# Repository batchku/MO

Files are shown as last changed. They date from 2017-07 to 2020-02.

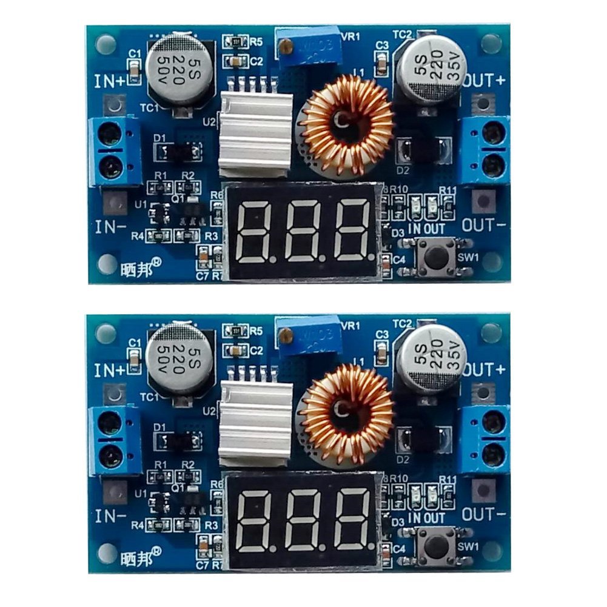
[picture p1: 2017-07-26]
PCBs/MO/_Pictures/PowerConv.jpg

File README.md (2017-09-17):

# MO
Mobile Objects for Music (MOM), Mobile Object for Drawing (MOD), and ...

## Installation

First: clone this repo:
```
git clone git@github.com:batchku/MO.git
```

Then: This repo relies on a [aLib-pd](https://github.com/batchku/aLib-pd) as a submodule. You can either clone that repo separately, or use this command within the MO repository to pull the submodule:

```
git submodule update --init --recursive
```
### nameChange.sh

To test for resulting name change use "test":

```./nameChanger.sh test searchTerm wordToReplaceWith```

To actually change use "change":

```./nameChanger.sh change searchTerm wordToReplaceWith```

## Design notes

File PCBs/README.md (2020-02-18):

# PCBs
###   GERBERS
Gerber files for PCB orders
###   MO
Board + Schem files for MO, this is the primary PCB collection
###   MOM
Board + Schem files specifically for MOM
###   Processor
Header, .txt, and XML file generator code

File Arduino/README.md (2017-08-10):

# Arduino
### MOD
Code base for MO modular system
### MOM
Code for MOM versions prior to MO modular system

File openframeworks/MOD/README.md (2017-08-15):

# livedraw-mini
openFrameworks based live video looper made for the Raspberry Pi 3, with a Pi Camera v2

# code
`ConsoleListener.h` - used for debugging in console on the Pi
`Consts.h` - definition of application parameters
`main.cpp` - application; set up openGL context, link to main class
`ofApp.cpp` - main functions for init, update and draw
`ofApp.h` - goes with ofApp.cpp
`Utils.cpp` - helper functions for math and such
`Utils.h` - goes with Utils.cpp
`vidLayer.cpp` - main class to handle a video layer; includes memory allocaiton, rendering, updating, and real-time control
`vidLayer.h` - goes with vidLayer.cpp

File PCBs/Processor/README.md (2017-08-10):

# Pin Mapping Generator
This python script generates the following header files for the arduino program [MOD.ino](https://github.com/batchku/MO/blob/master/Arduino/MOD/MOD.ino):
- [MO.H](https://github.com/batchku/MO/blob/master/PCBs/Processor/MO.h): defines a variable for each used pin
- [ARRAYS.H](https://github.com/batchku/MO/blob/master/PCBs/Processor/ARRAYS.h): defines arrays of all the related variables for easier coding
- [MIDI.h](https://github.com/batchku/MO/blob/master/PCBs/Processor/MIDI.h): defines midi note and control numbers for each pin

It also generates a text file for the [MO Pd abstractions](https://github.com/batchku/MO/tree/master/Pd/MO)
- [inputs.txt](https://github.com/batchku/MO/blob/master/PCBs/Processor/inputs.txt): defines MIDI values for UI elements in abstractions

# Coming...
- XML file for openFrameworks for MIDI mapping
- 

# Usage
1.  export a pinlist from eagle schematic, here called inputfile
2.  execute:
        ```python3 createFiles.py intputfile```

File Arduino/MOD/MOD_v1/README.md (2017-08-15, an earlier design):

# MOD Arduino code
Currently the MOD is hard-coded.

MIDI.h and MOD.h can be used from the [generator script](https://github.com/batchku/MO/blob/master/PCBs/Processor/createFiles.py) but DO NOT replace [Arrays.h](https://github.com/batchku/MO/blob/master/Arduino/MOD/Arrays.h).

In Tools of Arduino set:
* ```Board:``` to ```Teensy 3.6```
* ```USB Type:``` to ```Serial + MIDI```

# Coming Soon...
Modular class system for each aspect of the hardware. Classes will include: 
1. Strip
2. Actuator
3. User Interface (for components on shield)

### Ignore (for now)
* Strip.cpp/Strip.h
* MOBasic.cpp/MOBasic.h

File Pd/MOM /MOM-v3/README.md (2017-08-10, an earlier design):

# MOM
Running Puredata on the Raspberry Pi 3 computer

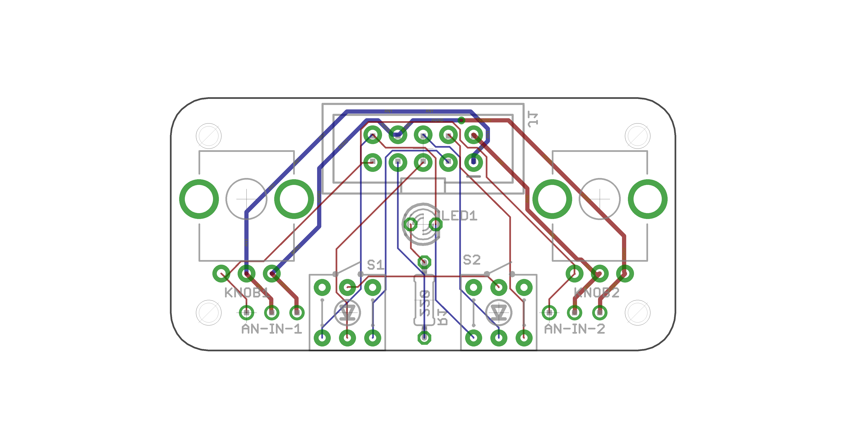
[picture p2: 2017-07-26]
PCBs/MO/_Pictures/MOD-v2-1_MOD-Strips.png

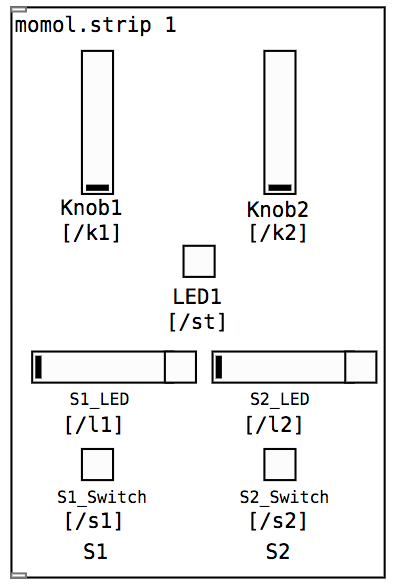
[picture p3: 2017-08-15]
Documentation/mo.strip.png

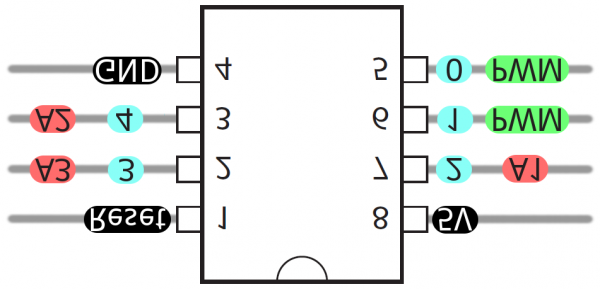
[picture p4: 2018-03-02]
Arduino/Raspi_Power_Tiny/tiny85.png

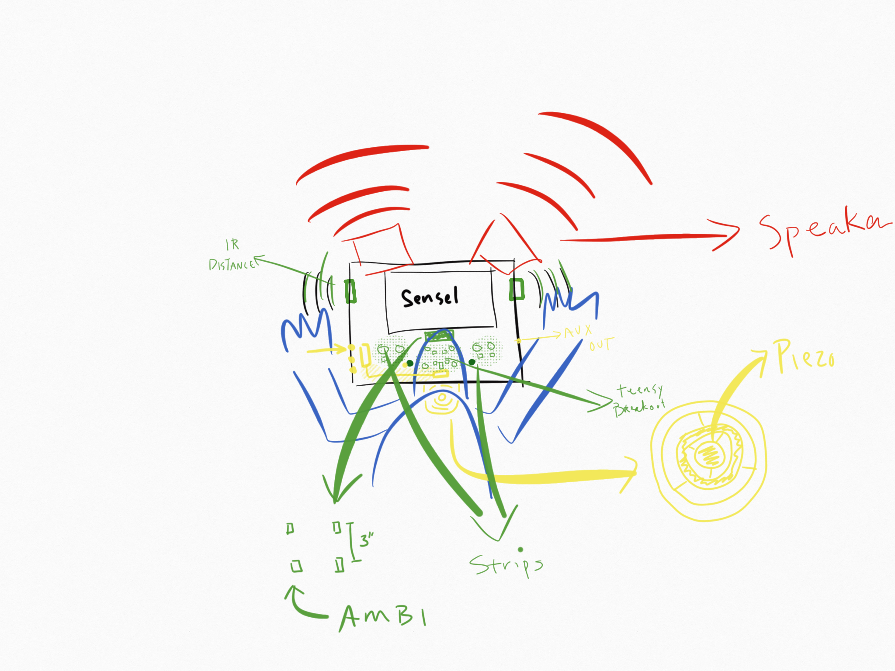
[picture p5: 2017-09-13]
Documentation/MOM_Sketch.jpg

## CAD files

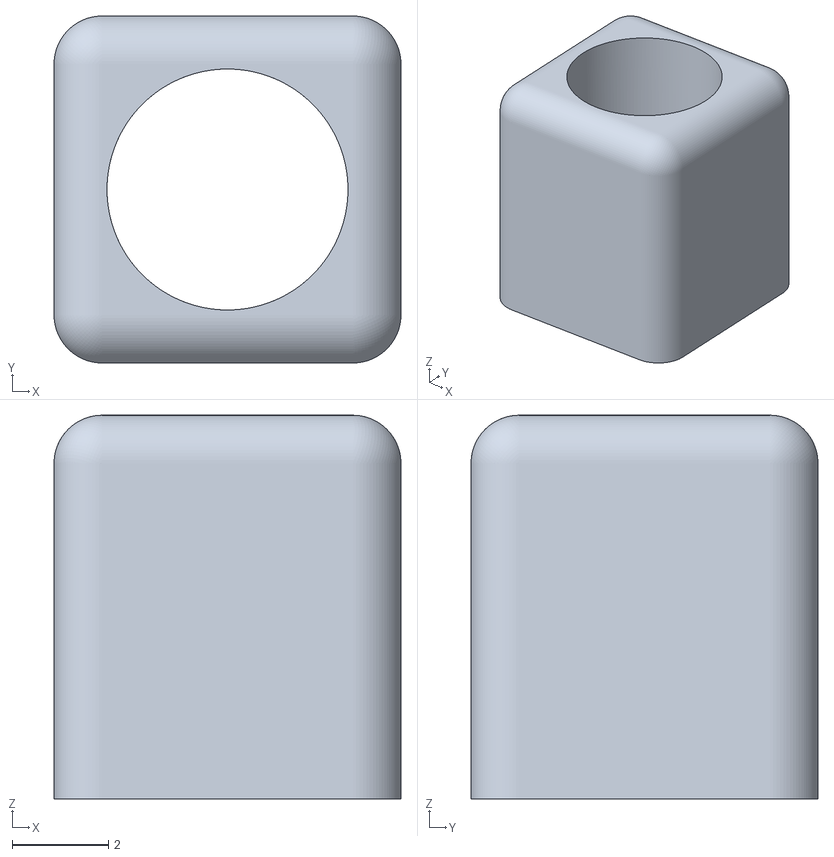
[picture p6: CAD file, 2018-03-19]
CAD/MOD/MOD v2/Button_wHole.stl
7.20 x 7.20 x 7.96

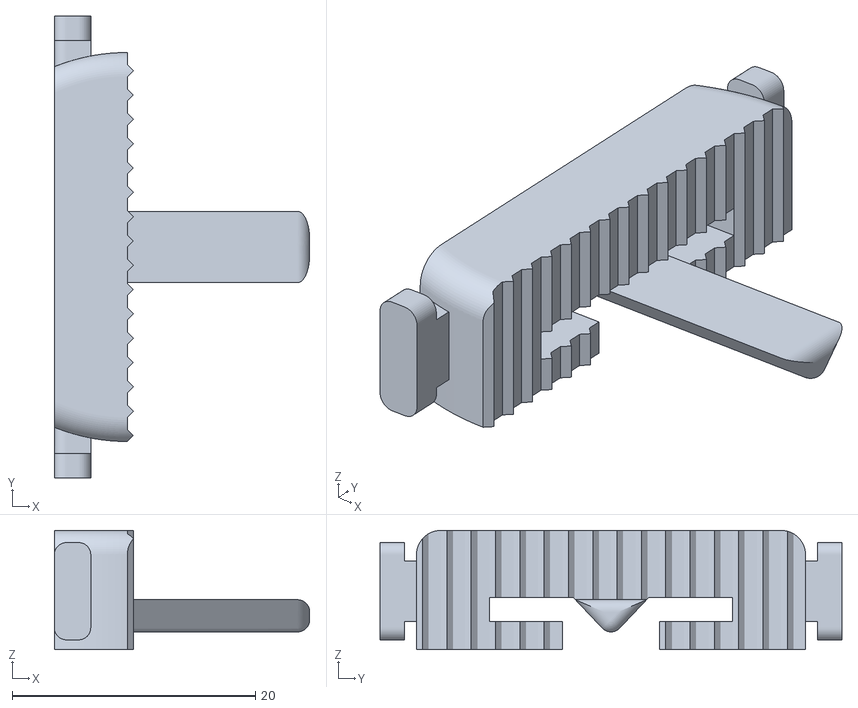
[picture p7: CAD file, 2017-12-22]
CAD/_exports/Clamp-female-4.stl
21.0 x 38.0 x 9.80

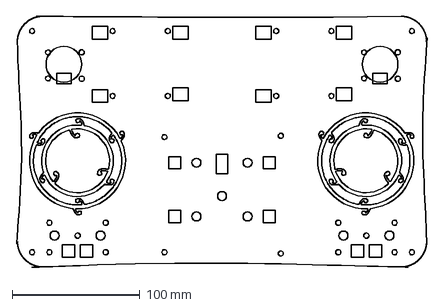
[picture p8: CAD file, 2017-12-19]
CAD/MOM/_exports/MOMv4_PCB-v2.6_01.dxf
321.5 x 196.7 mm

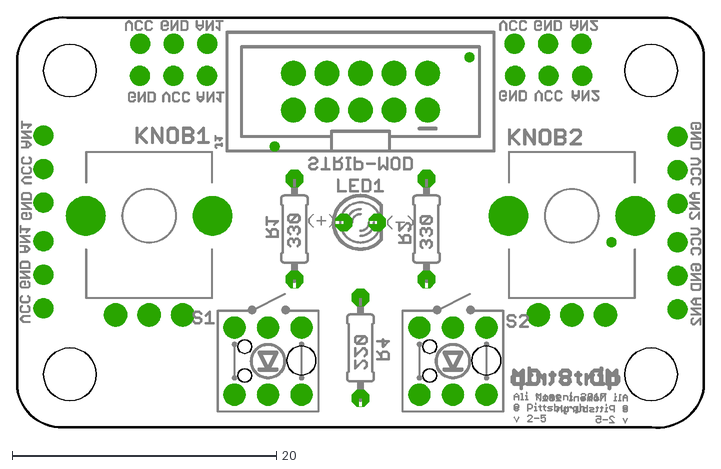
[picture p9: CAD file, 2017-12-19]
PCBs/MO/MO-v2-5_MOD-Strips.dxf
52.2 x 31.2

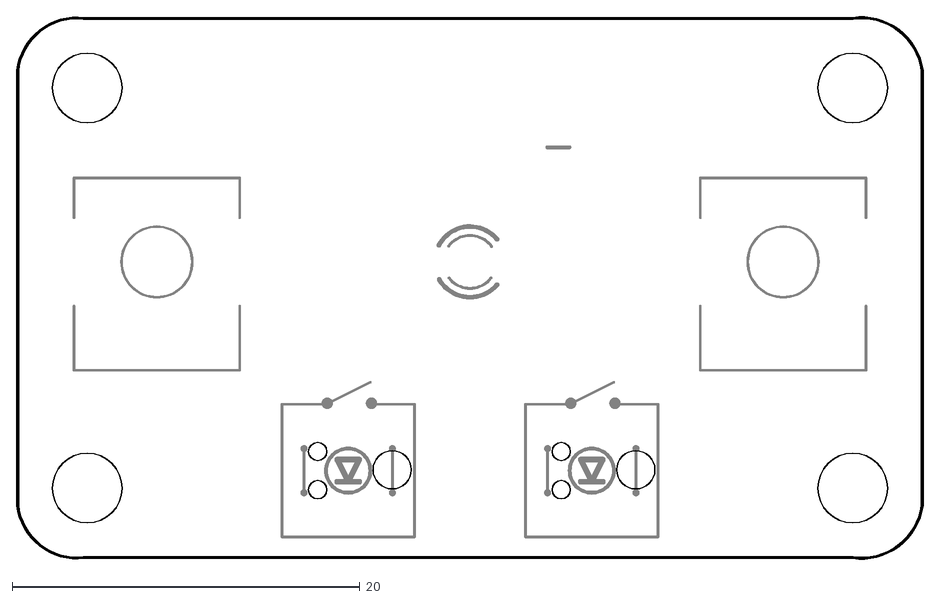
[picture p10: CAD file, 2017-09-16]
PCBs/MOD/MOD-v2-3_MOD-Strips.dxf
52.2 x 31.2

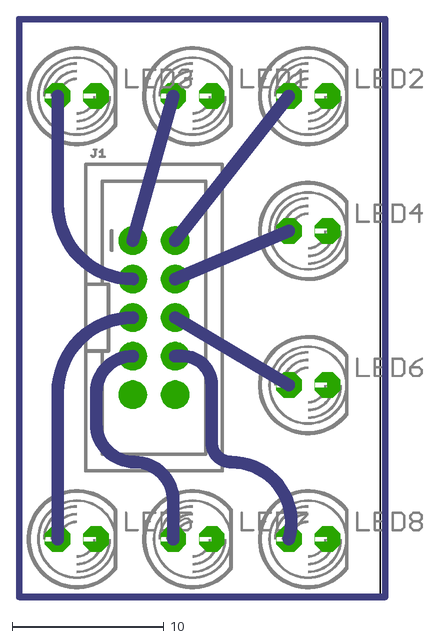
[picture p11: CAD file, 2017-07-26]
PCBs/MOM/MOM_LED-out_v04.dxf
26.8 x 38.5

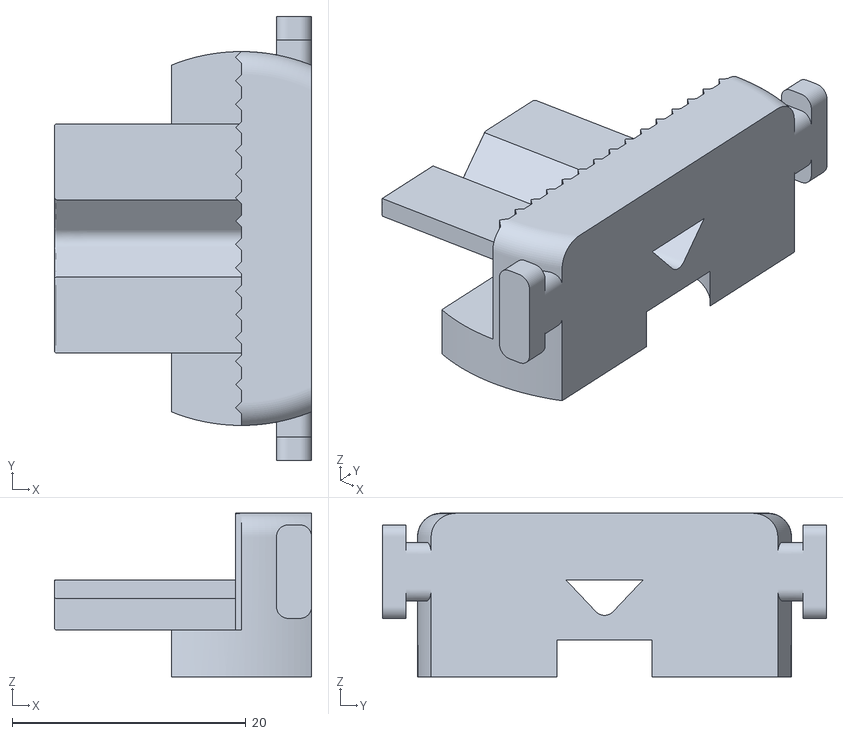
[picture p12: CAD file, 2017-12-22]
CAD/_exports/Clamp-male-3.stl
22.0 x 38.0 x 14.0

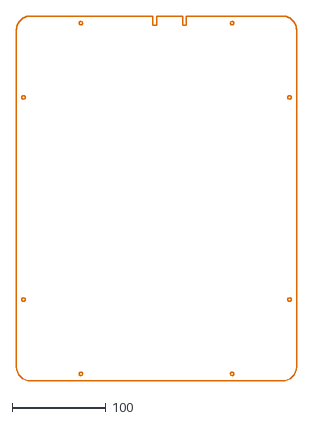
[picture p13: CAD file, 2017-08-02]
CAD/MOD/_MOD-vr_rhino-exports/MOD-v1_MOD-lightbox-bottom.dxf
299.0 x 389.5

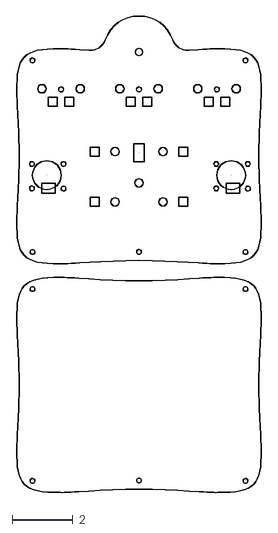
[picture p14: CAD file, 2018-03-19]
CAD/MOD/MOD v2/MODv2-1.1.dxf
8.05 x 15.7

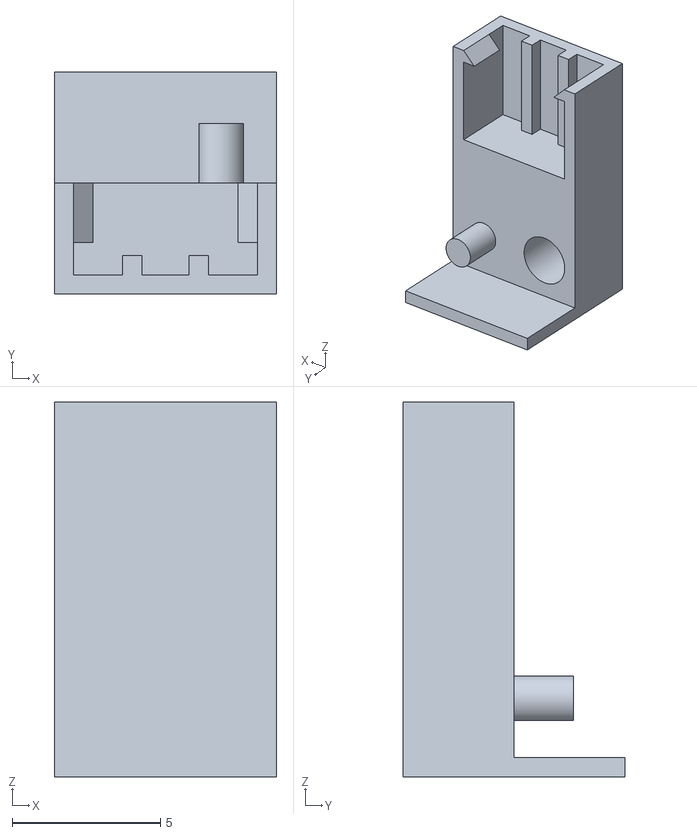
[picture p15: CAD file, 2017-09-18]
CAD/MOD/MOD-Button-Cap-Cap_v9-B.stl
7.50 x 7.50 x 12.6

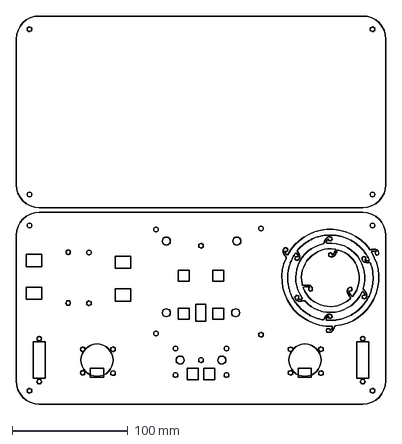
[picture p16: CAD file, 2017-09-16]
CAD/MOM/_exports/MOMv2_top-bottom-plate.dxf
320.0 x 335.9 mm

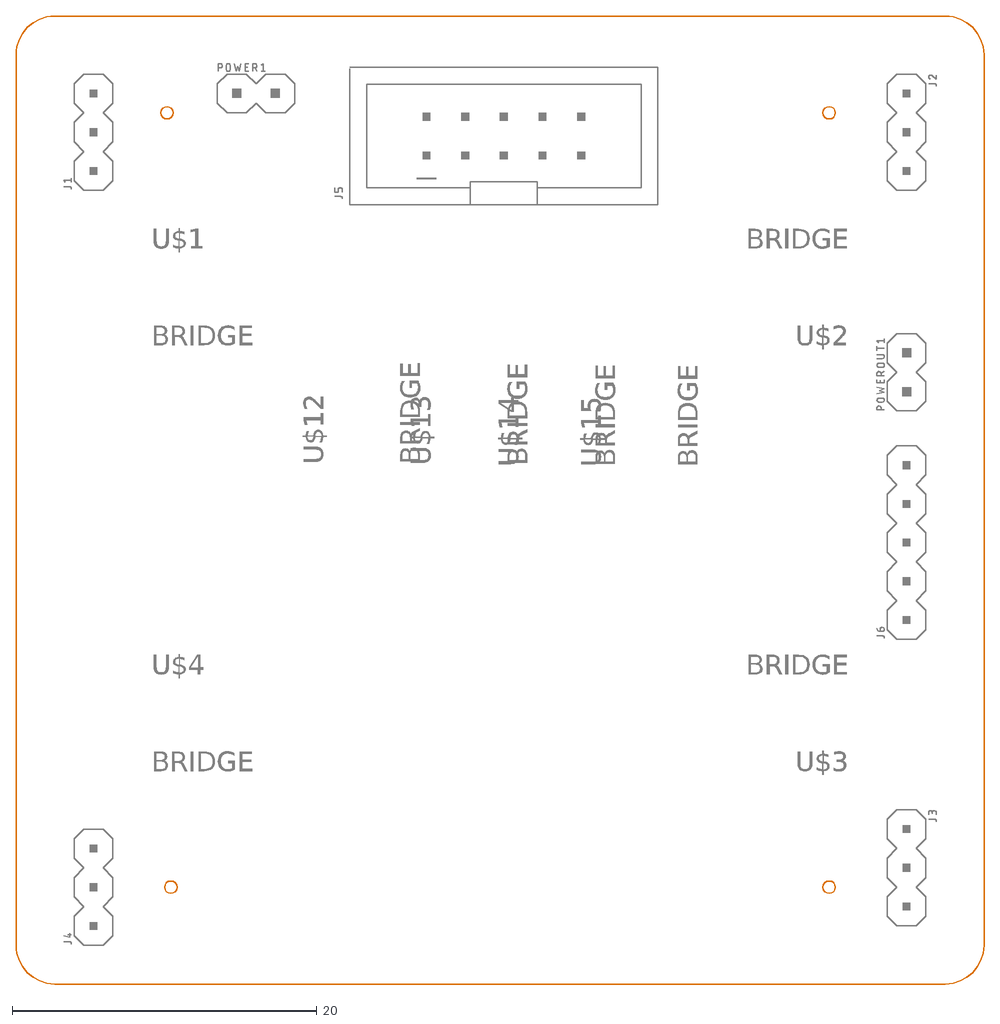
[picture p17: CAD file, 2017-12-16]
PCBs/MO/MO-bela-lightspace-A.dxf
U$1
BRIDGE
U$2
U$3
U$4
U$12
U$13
U$14
U$15

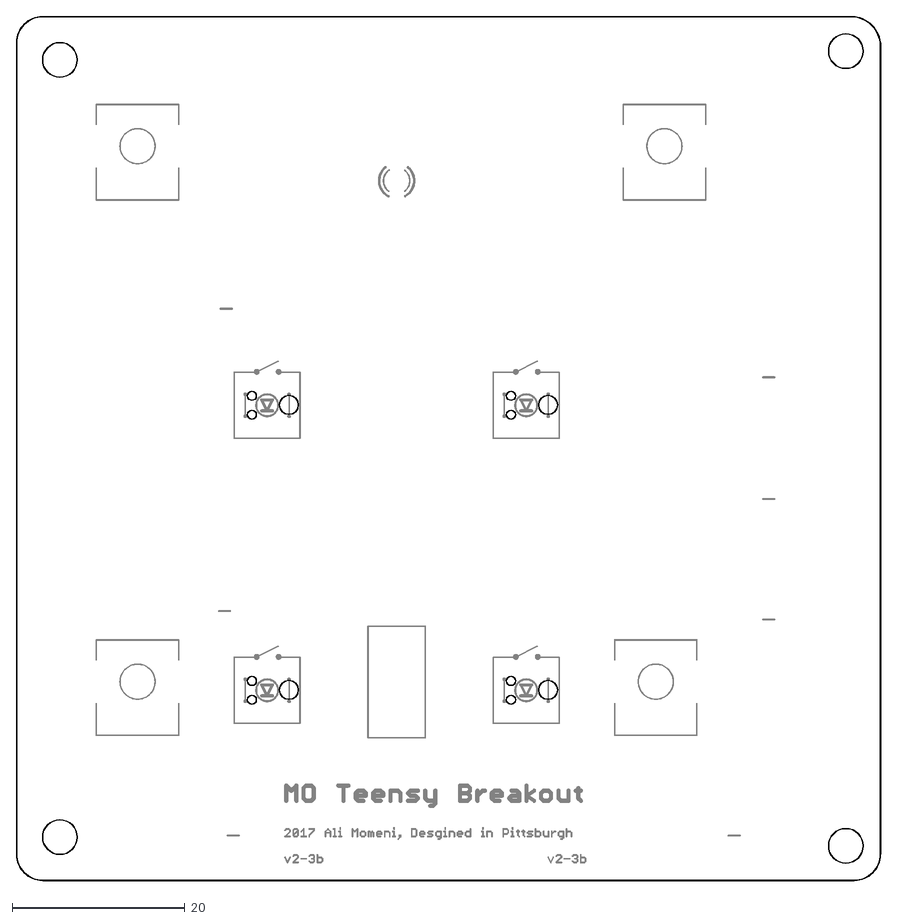
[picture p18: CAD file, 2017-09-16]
PCBs/MOD/MOD-v2-4.dxf
100.2 x 100.2

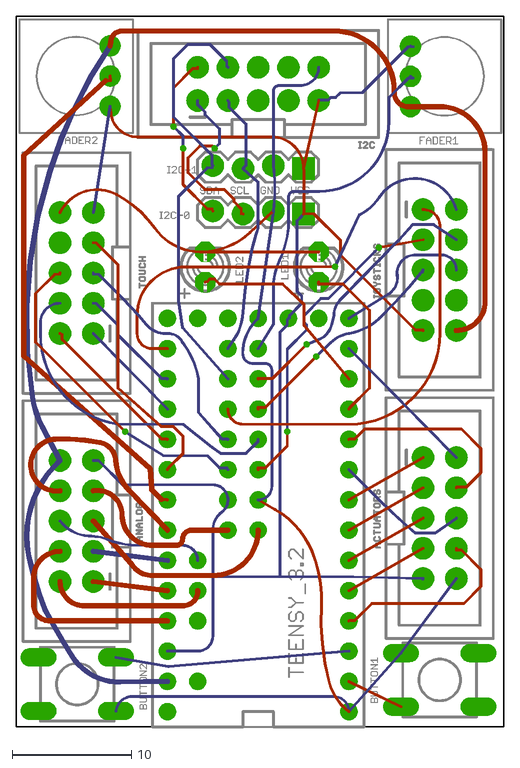
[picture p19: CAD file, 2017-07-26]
PCBs/MOM/MOM_teensy-breakout_v04.dxf
40.9 x 59.8

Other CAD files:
CAD/MOD/_MOD-vr_rhino-exports/MOD-v1_MOD-tech-pi-shelf.dxf
CAD/_exports/Clamp-female-3.stl
CAD/MOD/_MOD-vr_rhino-exports/MOD-v1_MOD-lightbox-mids.dxf
CAD/MOD/MOD-Button-Cap-Cap_v9-A.stl
CAD/MOD/Button-profile.dxf
CAD/MOD/MOD-Button-Cap-1.stl
CAD/MOD/MOD-Button-Cap-Cap-1.stl
CAD/MOD/MOD-Button-Cap-Cap_v6.stl
CAD/MOD/MOD-Button-Cap-Cap_v7.stl
CAD/MOD/MOD-Button-Cap-Cap_v8-A.stl
CAD/MOD/MOD-Button-Cap-Cap_v8-B.stl
CAD/MOD/MOD-Button-Cap-Frame_v4.stl
CAD/MOD/MOD-Button-Cap-Frame_v5.stl
CAD/MOD/MOD-Button-Cap-Frame_v6.stl
CAD/MOD/MOD-Button-Frame-1.stl
CAD/MOD/MOD-holder_all-v3-4.dxf
CAD/MOD/MOD-v1.1-neck-v3-2a.dxf
CAD/MOD/MOD-v1.1.dxf
CAD/MOD/MOD-v1.1a.dxf
CAD/MOD/MOD-v1.1b.dxf
CAD/MOD/MOD-v1.1c.dxf
CAD/MOD/MOD-v1.1d.dxf
CAD/MOD/MOD-v1.dxf
CAD/MOD/MOD-v1_button-cap.3dm
CAD/MOD/MOD-v1_button-cap.obj
CAD/MOD/MOD-v1_button-cap.stl
CAD/MOD/MOD-v1_button-cap2.stl
CAD/MOD/MOD-v1_button-cap3.stl
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

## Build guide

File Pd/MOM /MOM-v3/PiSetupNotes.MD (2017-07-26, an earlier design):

#### Step 1.
Download [Raspbian Jessie with Pixel](https://www.raspberrypi.org/downloads/raspbian/), the most current operating system for the Pi.  If the opening the zip file on your Mac results in cpgz file rather than an img file then try opening in a third party unarchiving app like [this one](https://itunes.apple.com/us/app/the-unarchiver/id425424353?mt=12).

#### Step 2.
Copy the OS to an SD card.  If you're doing this on a Mac I recommend using the [Pi Filler](http://ivanx.com/raspberrypi/) app for this.

#### Step 3.  
Boot your Pi.  Log in as user:```pi```, pass:```raspberry```.  If you wanna put your Pi on CMU WiFi you'll need to register it at [https://netreg.net.cmu.edu](https://netreg.net.cmu.edu).  Register a new machine on the Legacy Wireless Network (the one that shows up as "CMU").  The HWAddr can be found be entering the following command in the terminal:

    ifconfig

Look for the wlan0 section and copy the HWaddr (it will look something like b8:27:eb:3e:cf:b9)

It will take 20 to 45 minutes for you machine to be registered and able to connect to the net on the CMU network.

#### Step 4.  
Configurate the Pi:

You may wish to configure your keyboard in Preferences/keyboard.   You may also wish to change your password using Preferences/Raspi configuration (I'm using ```3.14ispi```).  Enable SSH on the Pi under Preferences/RaspberryPi configuration.

#### Step 5.
Install PD vanilla using the terminal:

```sudo apt-get update```
```sudo apt-get install puredata```

#### Step 6.  
Install TightVNCserver:

```sudo apt-get install tightvncserver```

#### Step 7.
To copy files to your Pi from a Mac using an ethernet cable set up both machine with static IP addresses [here](https://www.modmypi.com/blog/how-to-give-your-raspberry-pi-a-static-ip-address-update)'s how to do it on a Pi. Give every Pi a unique IP address.

 Then you can SSH in from mac terminal: ```ssh pi@10.0.0.2``` where you can start vncserver ```vncserver``` which will allow you to screenshare (on the Mac this is done by "connect to server" [Apple K] and entering vnc://10.0.0.2:5901).  

 To copy files from the Mac to the Pi in mac terminal: scp -r /Users/jessestiles/Documents/Github/CHIPD pi@10.0.0.2:Documents

#### Step 8.  
Set up PD preferences to add necessary directories.

#### Step 9.  
Make a script to open your pd patch with all the right configs.

1) create an executable script that opens PD:

2) Create a /bin folder in your home/pi folder by typing this :

```mkdir ./bin``` (hit enter)

3) Move to this folder by typing :

```cd ./bin```

4) Create a file in this folder named “script_pd” (or whatever you want to call this) :

```sudo nano script_pd``` (this opens a blank text file in the nano editor)

5) In the nano editor, type this script :

```
#!/bin/bash
# This script will start Pd
echo "Starting Pd..."
pd -rt -r 44100 -audiodev 5 -mididev 1 -inchannels 1 -outchannels 2 /home/pi/Documents/PD/launch.pd &
```

6) Save your script by pressing Ctrl+X, hitting y, and Enter.
7) This script is still nothing but a text file. We need to make it executable by typing this :

```sudo chmod 755 script_pd```

Step 10.  Make pi run the script on startup: add the executable script to /etc/profile

Once your Pi is all set up you can copy the entire machine using [Pi Copier](http://ivanx.com/raspberrypi/) and duplicate it onto new SD cards using Pi Filler.

Step 11.  Making the Pi join automatically join a network that you create.

```sudo nano /etc/network/interfaces```

Add new first line:

```auto wlan0```

then do ```sudo nano /etc/wpa_supplicant/wpa_supplicant.conf```

and add the following:

    network={
    ssid="YOUR_NETWORK_NAME"
    psk="YOUR_NETWORK_PASSWORD"
    proto=RSN
    key_mgmt=WPA-PSK
    pairwise=CCMP
    auth_alg=OPEN
    }

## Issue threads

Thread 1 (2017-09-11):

A2982 $U2 missing shorted ground

batchku, 2017-09-11:
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

must fix in schematic and board

Closed 2017-09-15.

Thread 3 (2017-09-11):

relay footprint has wrong size holes

batchku, 2017-09-11:
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

component: RELAY-OMRON-G6DN

the two smaller holes (the ones for control, not power) are too small.
the need to be bigger

Closed 2017-09-15.

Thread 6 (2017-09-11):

+5V-Battery not connected to anything

organnoise, 2017-09-11:
remove ```+5V-Battery``` which is connected to ATTINY85 and SW2, replace it with ```+5V```
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

Closed 2017-09-15.

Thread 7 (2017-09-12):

A2982 schematic component error

batchku, 2017-09-12:
Pin numbers on the output side of the A2982 are wrong.

This is what it looks like:

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

This is what it should look like:

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

-pins 10 and 11 and not connected;

Closed 2017-09-15.

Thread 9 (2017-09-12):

AN1/AN2 Mislabeled

organnoise, 2017-09-12:
AN1/AN2 reverse labeled on board silkscreen

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

Closed 2017-09-15.

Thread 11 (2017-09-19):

Strip Order

organnoise, 2017-09-19:
Strips are ordered:
1
4
3
2

on right side of board.
This isn't wrong, but not the most sensical

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

batchku, 2017-09-24:
fixed in v2-5

Closed 2017-09-24.

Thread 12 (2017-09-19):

Pot + Button Arrangement

organnoise, 2017-09-19:
Pot + Buttons start in the bottom right corner (AN 9, BTN 13). Strange place, it would make more sense if it was in the top left. This can be fixed in code if need be.

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

batchku, 2017-09-24:
fixed in v2-5

Closed 2017-09-24.

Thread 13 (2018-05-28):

Flip - and + positions for Joystick

organnoise, 2018-05-28:
Wrong:
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

It should be the other way:
```
-
+
```
A big problem is that this still works, but it reverses the output of the joysticks so the data seems to be in reverse.

Also, the button doesn't work as the MCU watches for a falling edge to detect a button being pressed.

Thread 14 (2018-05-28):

Keep Joystick inputs orientation the same

organnoise, 2018-05-28:
Wrong:
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
This can be found on the RIGHT side of the board.

Right:
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

This can be found on the LEFT side of the board and should be duplicated to the other side of the board to be the same.

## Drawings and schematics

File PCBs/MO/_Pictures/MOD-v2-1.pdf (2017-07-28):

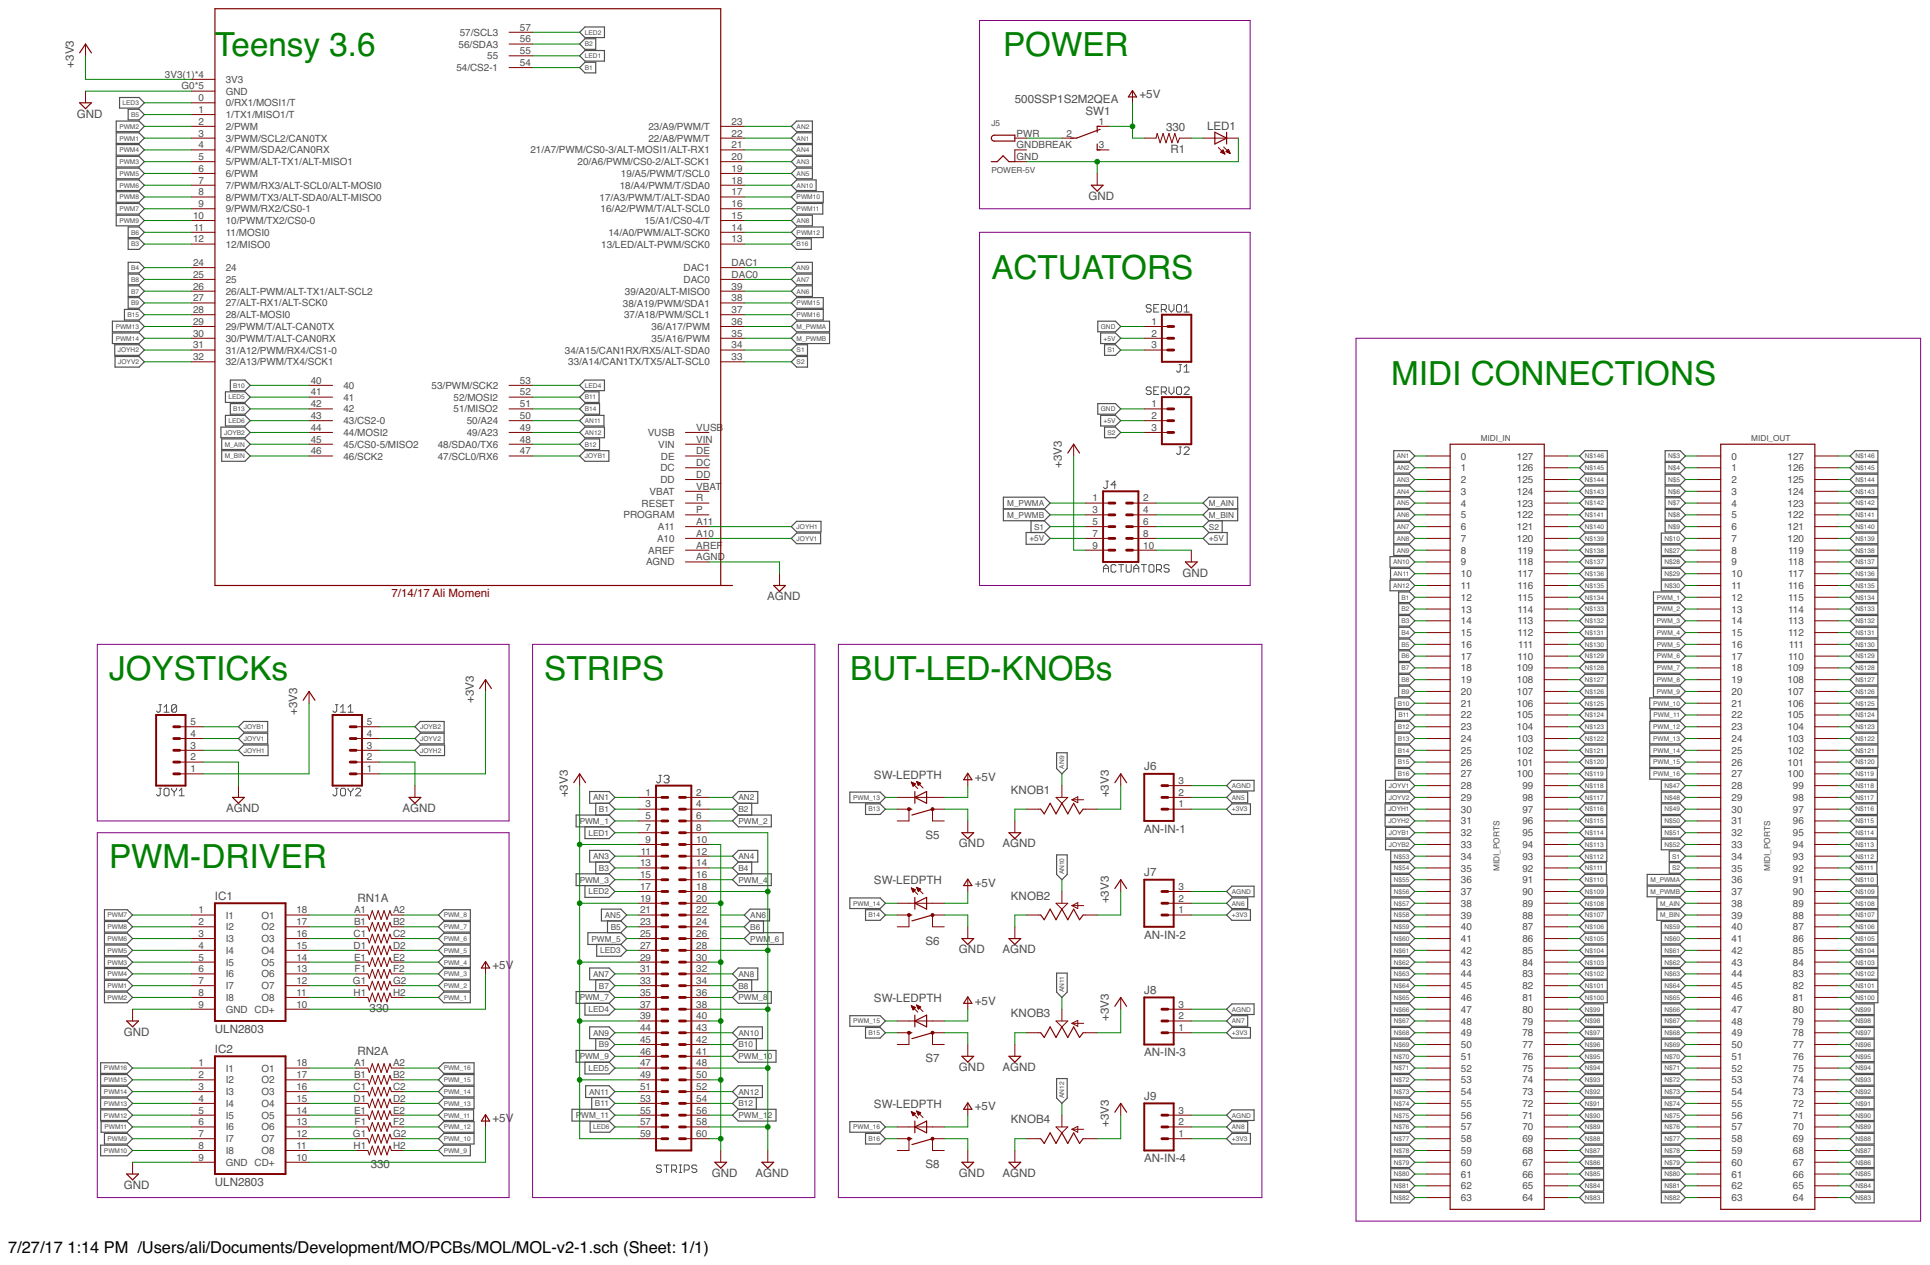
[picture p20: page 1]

7/27/17 1:14 PM /Users/ali/Documents/Development/MO/PCBs/MOL/MOL-v2-1.sch (Sheet: 1/1)

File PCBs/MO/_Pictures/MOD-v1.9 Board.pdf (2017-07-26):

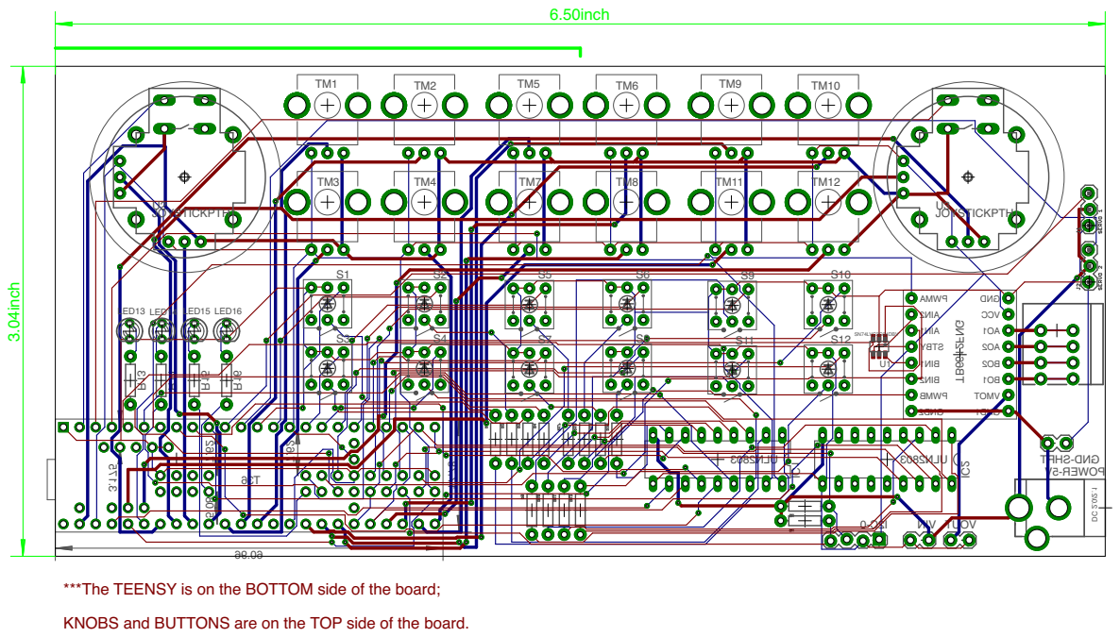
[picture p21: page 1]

***The TEENSY is on the BOTTOM side of the board;

KNOBS and BUTTONS are on the TOP side of the board.

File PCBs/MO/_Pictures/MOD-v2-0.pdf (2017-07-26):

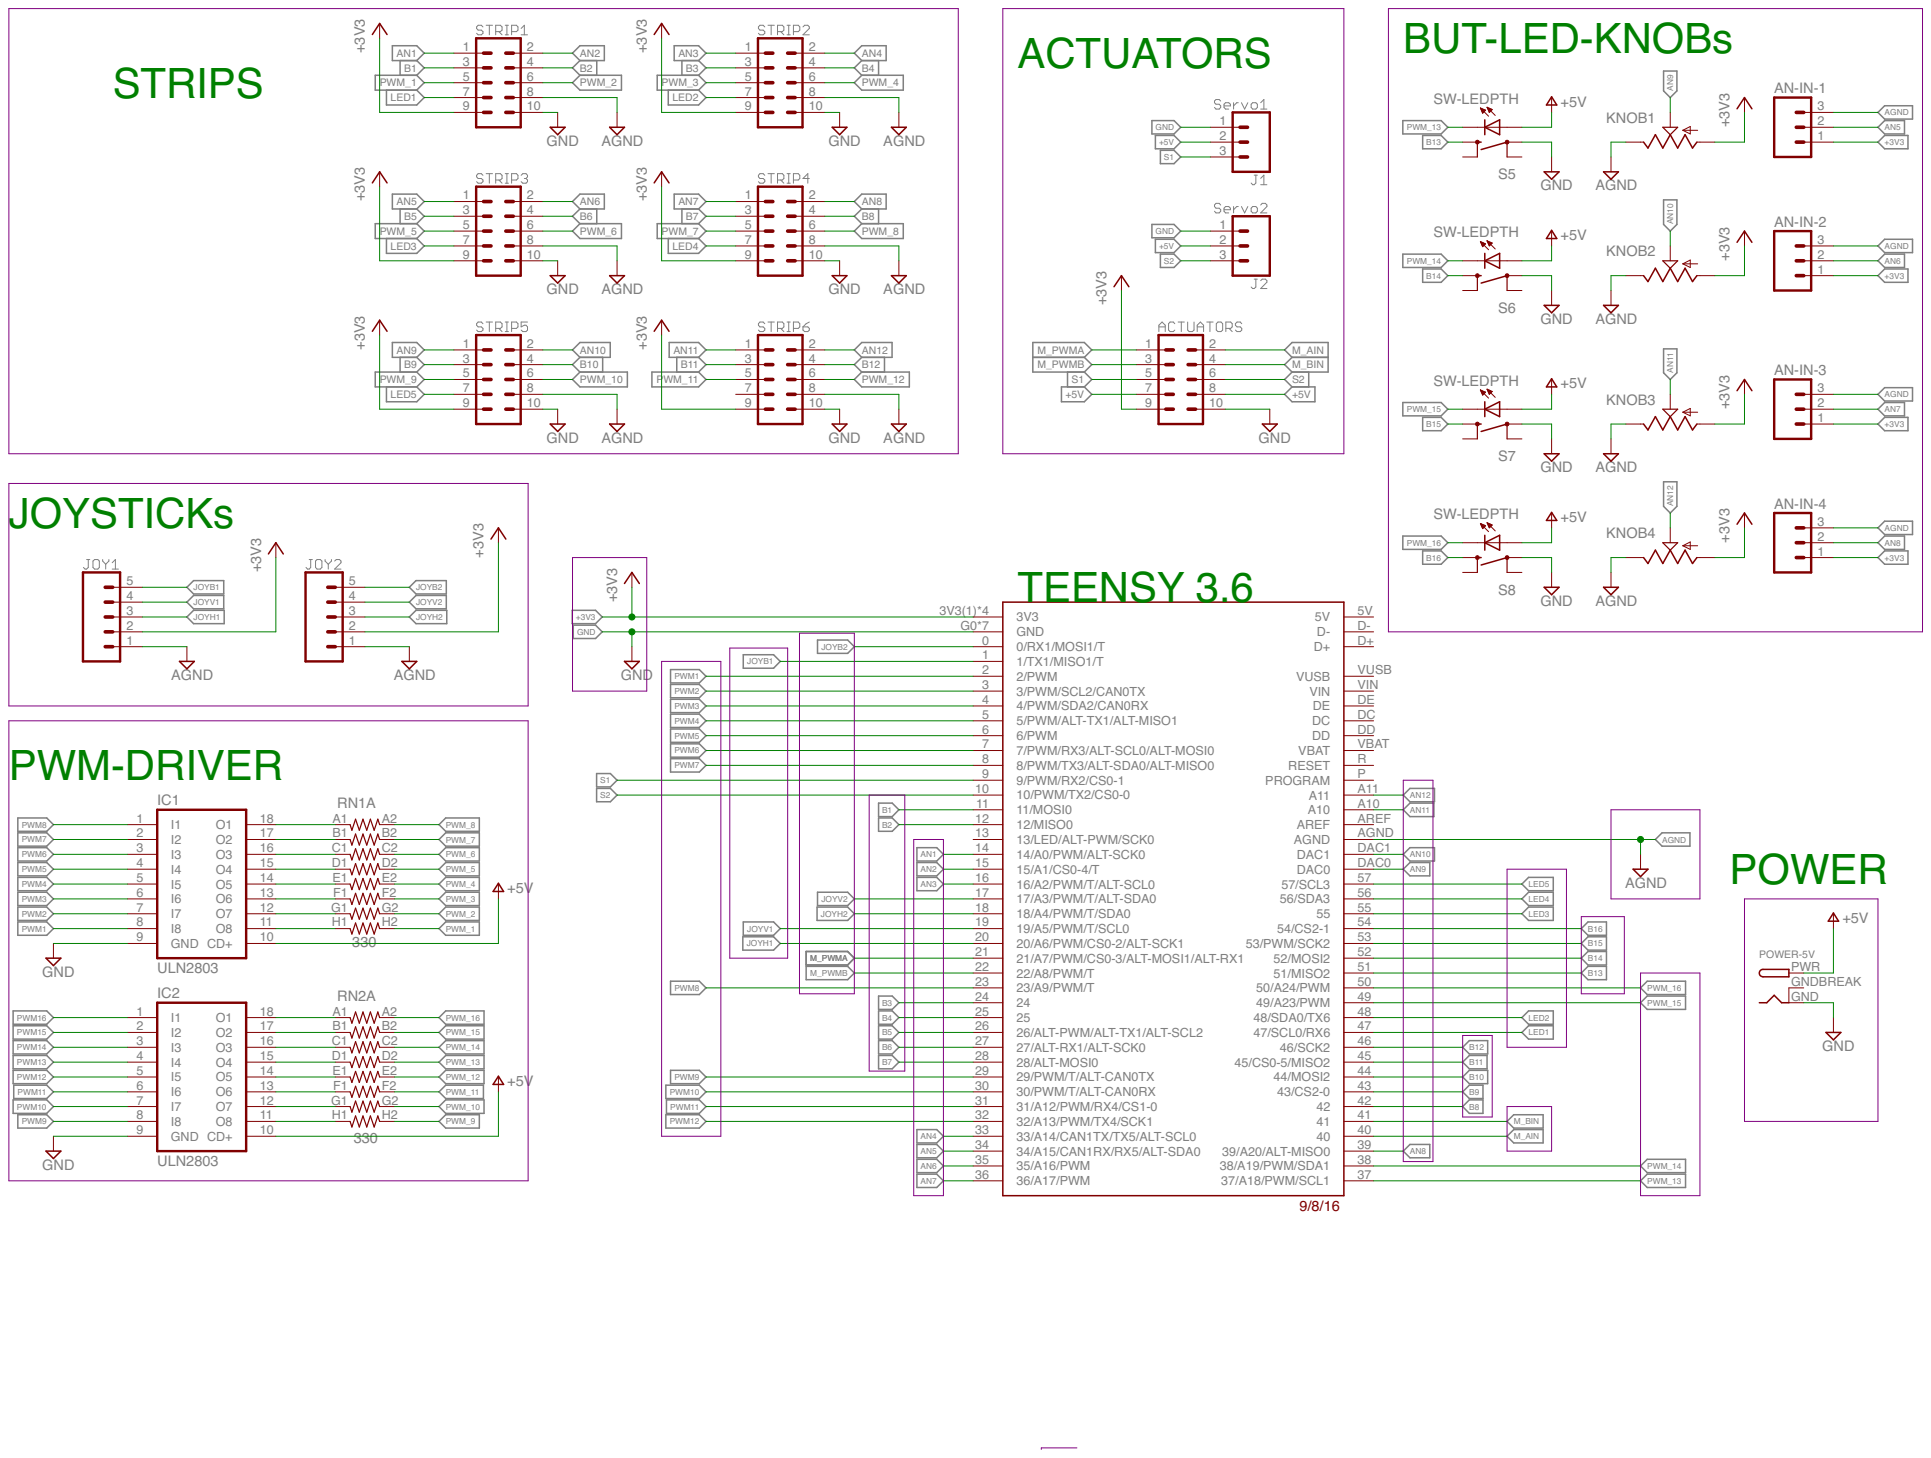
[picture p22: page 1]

JOYB2 | 1/TX1/MISO1/T 1

S1 | | 10/PWM/TX2/CS0-0 10
S2 | | | 11/MOSI0 11 | AN12

19/A5/PWM/T/SCL0 19
20/A6/PWM/CS0-2/ALT-SCK1 20

M_PWMA | | B14

M_PWMB | | B13

AN6 | PWM_14

AN7 | PWM_13

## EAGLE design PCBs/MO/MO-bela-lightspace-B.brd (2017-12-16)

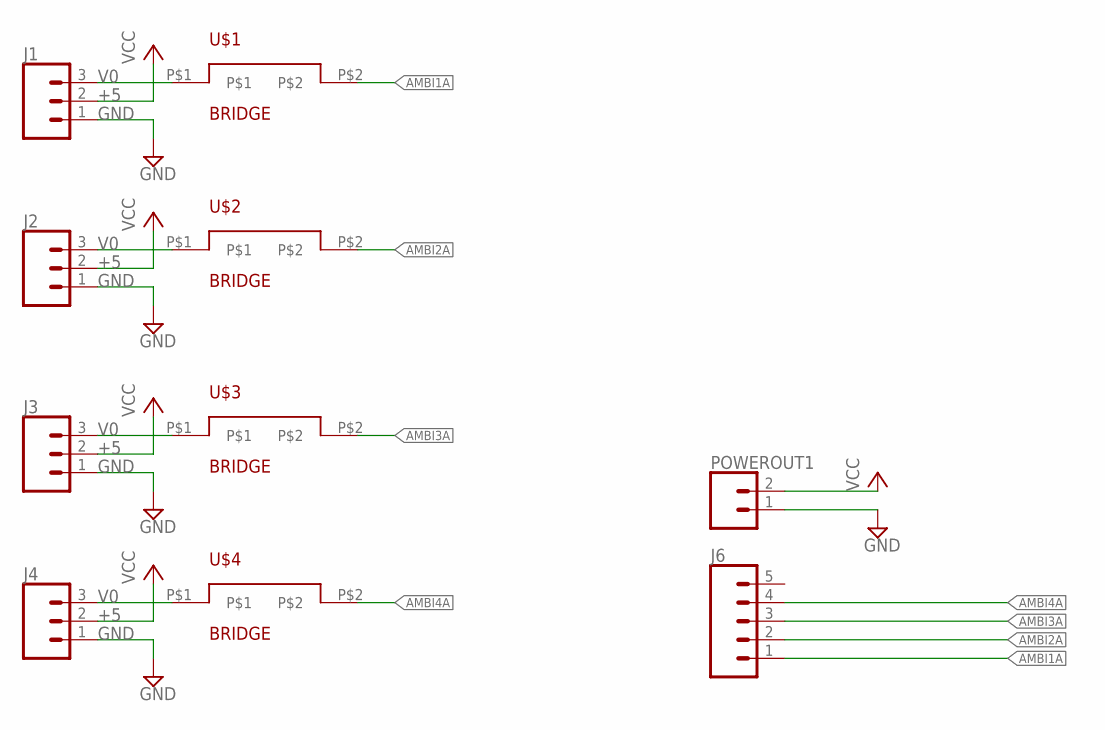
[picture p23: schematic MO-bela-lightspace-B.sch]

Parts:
J1, J2, J3, J4: CONN_03LOCK; 1X03_LOCK
J6: CONN_05LOCK; 1X05_LOCK
POWEROUT1: CONN_02LOCK; 1X02_LOCK
U$1, U$2, U$3, U$4: BRIDGE

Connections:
AMBI1A: J6.1, U$1.P$2
AMBI2A: J6.2, U$2.P$2
AMBI3A: J6.3, U$3.P$2
AMBI4A: J6.4, U$4.P$2
GND: J1.1, J2.1, J3.1, POWEROUT1.1
MNOVE: J4.1
unnamed: J1.3, U$1.P$1
unnamed: J2.3, U$2.P$1
unnamed: J3.3, U$3.P$1
unnamed: J4.3, U$4.P$1
VCC: J1.2, J2.2, J3.2, J4.2, POWEROUT1.2

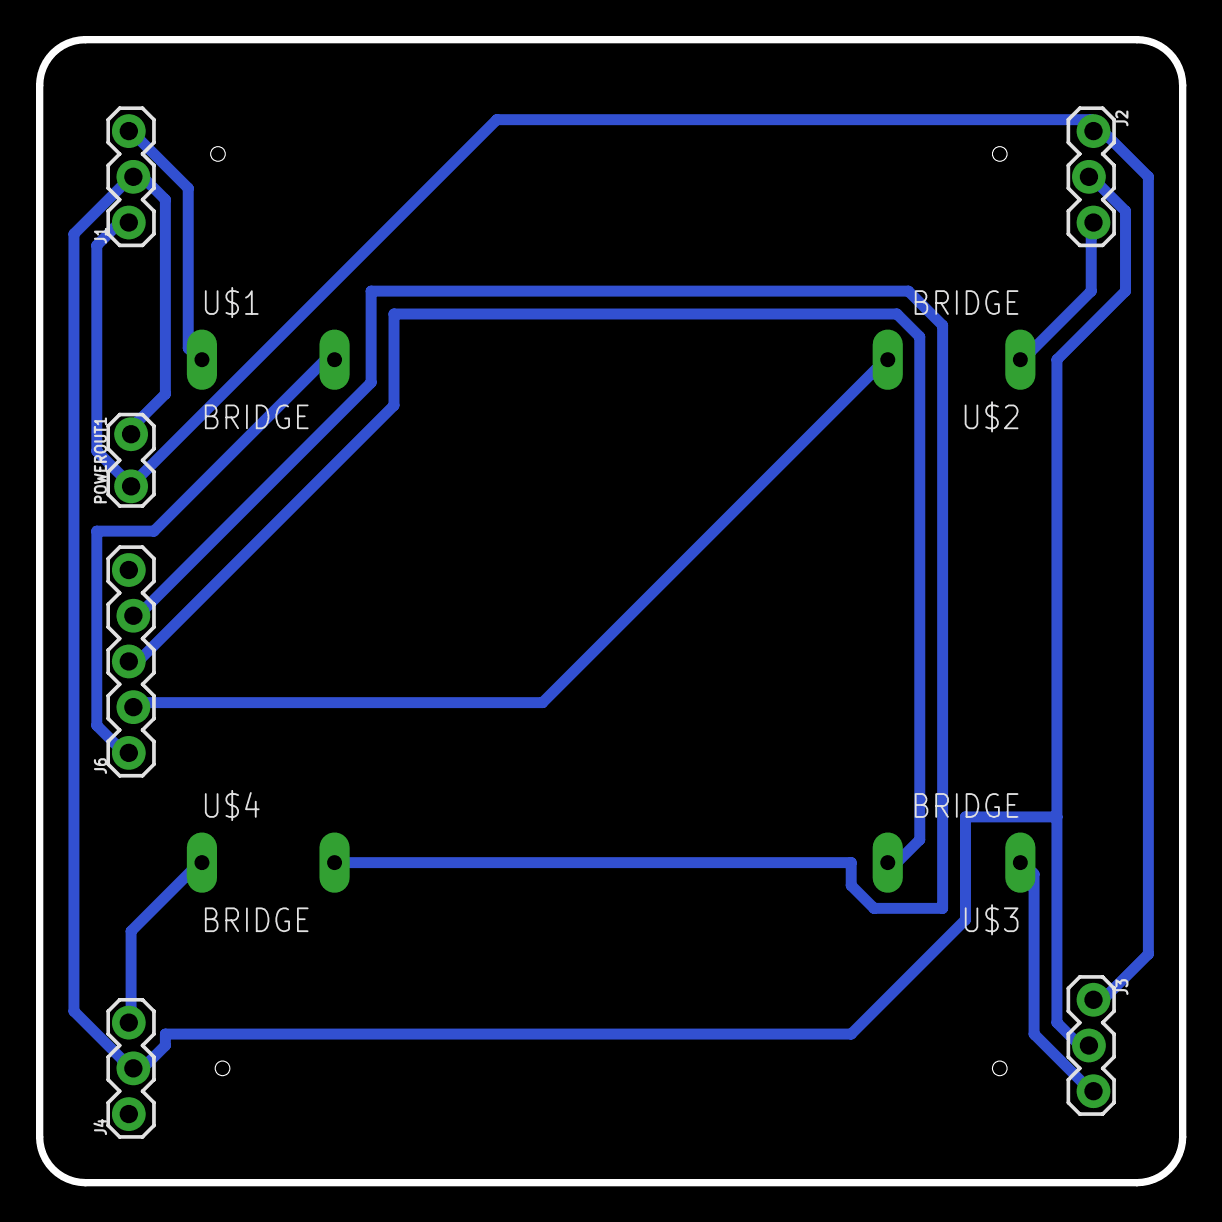
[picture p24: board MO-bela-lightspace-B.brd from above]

Board: 2 copper layers, 63.5 x 63.5 mm, 10 parts (0 on the bottom side), 10 nets.

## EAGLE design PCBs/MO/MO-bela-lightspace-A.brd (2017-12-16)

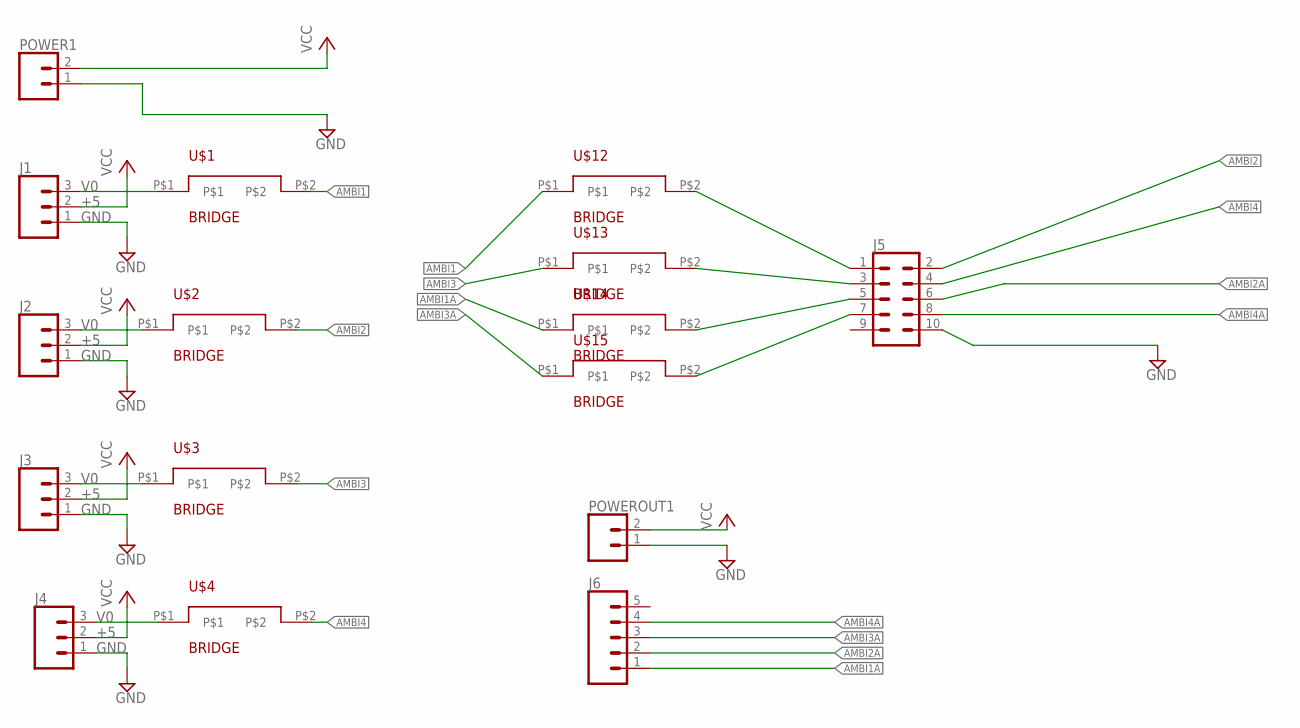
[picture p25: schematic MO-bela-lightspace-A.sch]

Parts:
J1, J2, J3, J4: CONN_03LOCK; 1X03_LOCK
J5: CONN_05X2SHD_LOCK; 2X5-SHROUDED_LOCK
J6: CONN_05LOCK; 1X05_LOCK
POWER1: CONN_02LOCK; 1X02_LOCK
POWEROUT1: CONN_02LOCK; 1X02_LOCK
U$1, U$2, U$3, U$4, U$12, U$13, U$14, U$15: BRIDGE

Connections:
AMBI1: U$1.P$2, U$12.P$1
AMBI1A: J6.1, U$14.P$1
AMBI2: J5.2, U$2.P$2
AMBI2A: J5.6, J6.2
AMBI3: U$3.P$2, U$13.P$1
AMBI3A: J6.3, U$15.P$1
AMBI4: J5.4, U$4.P$2
AMBI4A: J5.8, J6.4
GND: J1.1, J2.1, J3.1, J4.1, J5.10, POWER1.1, POWEROUT1.1
unnamed: J1.3, U$1.P$1
unnamed: J2.3, U$2.P$1
unnamed: J3.3, U$3.P$1
unnamed: J4.3, U$4.P$1
unnamed: J5.1, U$12.P$2
unnamed: J5.3, U$13.P$2
unnamed: J5.5, U$14.P$2
unnamed: J5.7, U$15.P$2
VCC: J1.2, J2.2, J3.2, J4.2, POWER1.2, POWEROUT1.2

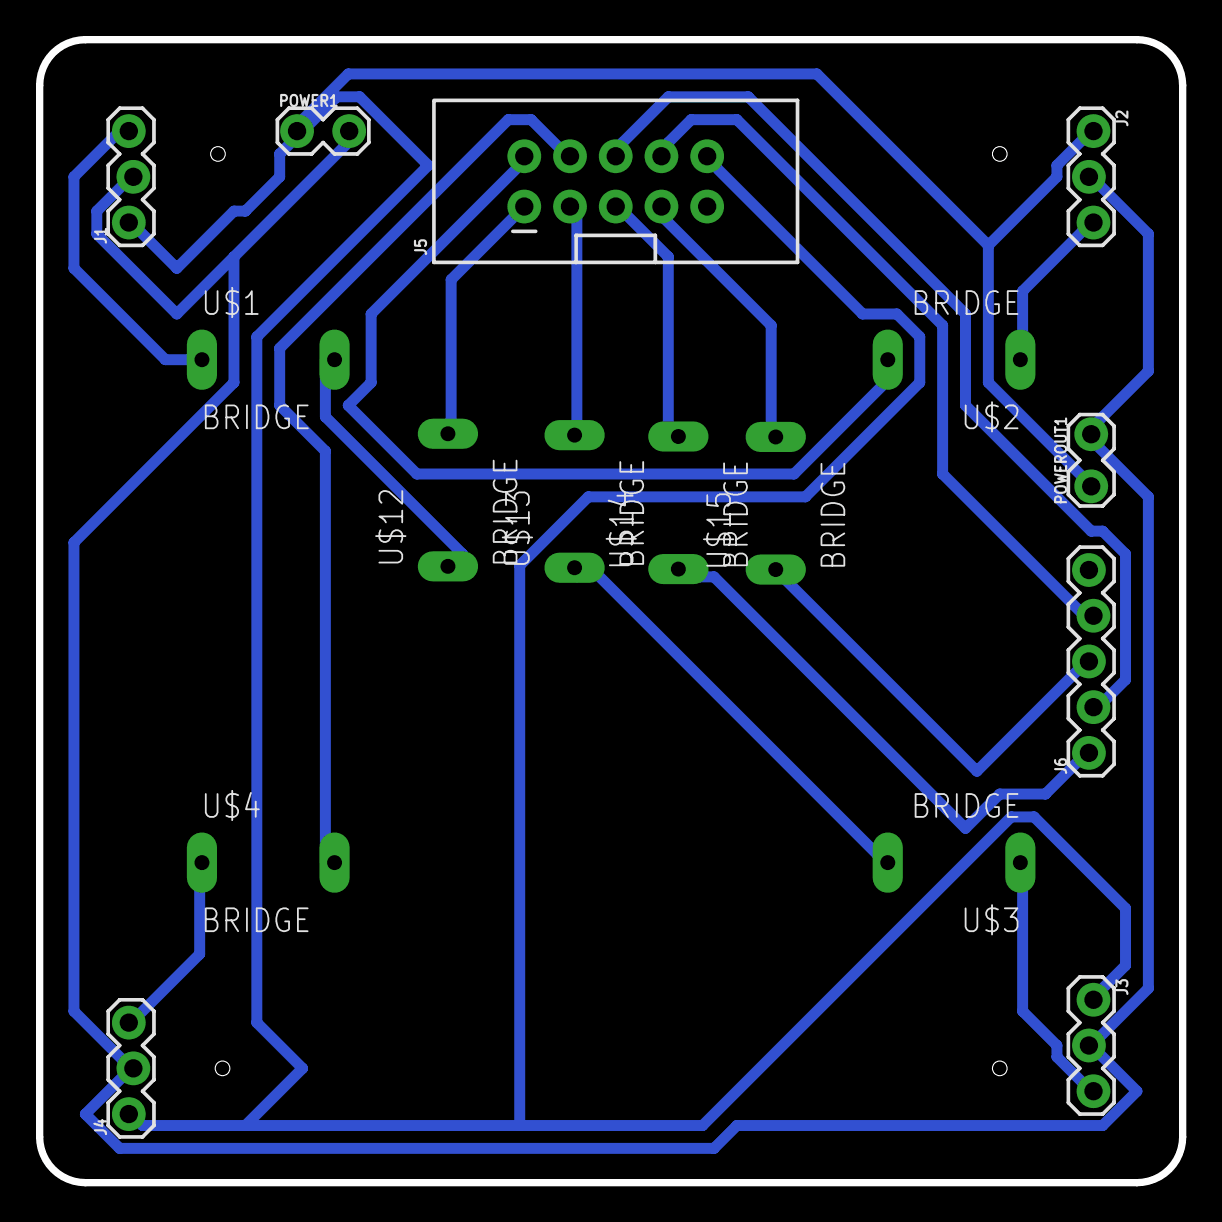
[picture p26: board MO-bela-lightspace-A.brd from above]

Board: 2 copper layers, 63.5 x 63.5 mm, 16 parts (0 on the bottom side), 18 nets.

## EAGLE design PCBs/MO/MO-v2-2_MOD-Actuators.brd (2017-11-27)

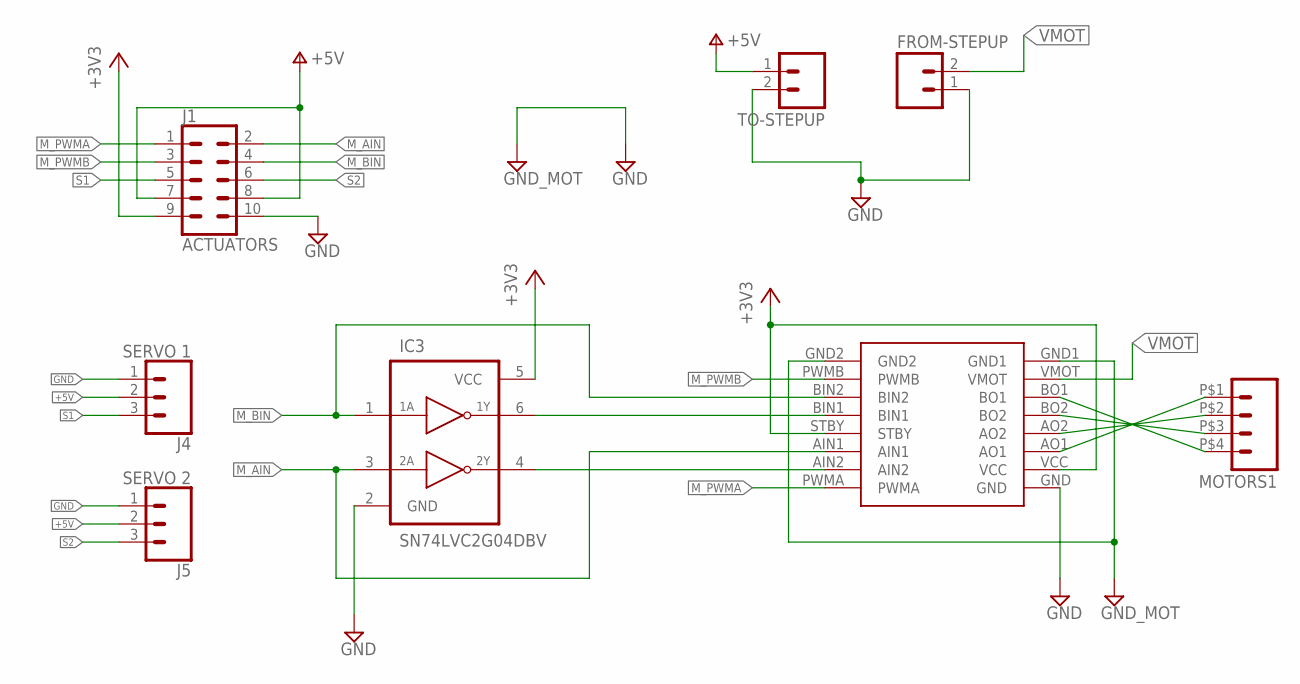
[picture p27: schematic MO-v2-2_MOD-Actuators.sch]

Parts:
FROM-STEPUP: M02LOCK; 1X02_LOCK
IC3: SN74LVC2G04DBV; SOT23-6
J1: ACTUATORS; 2X5-SHROUDED_LOCK
J4: SERVO 1; 1X03_LOCK@1
J5: SERVO 2; 1X03_LOCK@1
MOTORS1: M04; SPRINGTERMINAL-2.54MM-4
TO-STEPUP: M02LOCK; 1X02_LOCK
U$7: POLOLU_TB6612FNG

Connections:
+3V3: IC3.5 (VCC), J1.9, U$7.STBY, U$7.VCC
+5V: J1.7, J1.8, J4.2, J5.2, TO-STEPUP.1
GND: FROM-STEPUP.1, IC3.2 (GND), J1.10, J4.1, J5.1, TO-STEPUP.2, U$7.GND
GND_MOT: U$7.GND1, U$7.GND2
M_AIN: IC3.3 (2A), J1.2, U$7.AIN1
M_BIN: IC3.1 (1A), J1.4, U$7.BIN2
M_PWMA: J1.1, U$7.PWMA
M_PWMB: J1.3, U$7.PWMB
unnamed: MOTORS1.P$1 (1), U$7.AO1
unnamed: MOTORS1.P$2 (2), U$7.AO2
unnamed: MOTORS1.P$3 (3), U$7.BO2
unnamed: MOTORS1.P$4 (4), U$7.BO1
unnamed: IC3.6 (1Y), U$7.BIN1
unnamed: IC3.4 (2Y), U$7.AIN2
S1: J1.5, J4.3
S2: J1.6, J5.3
VMOT: FROM-STEPUP.2, U$7.VMOT

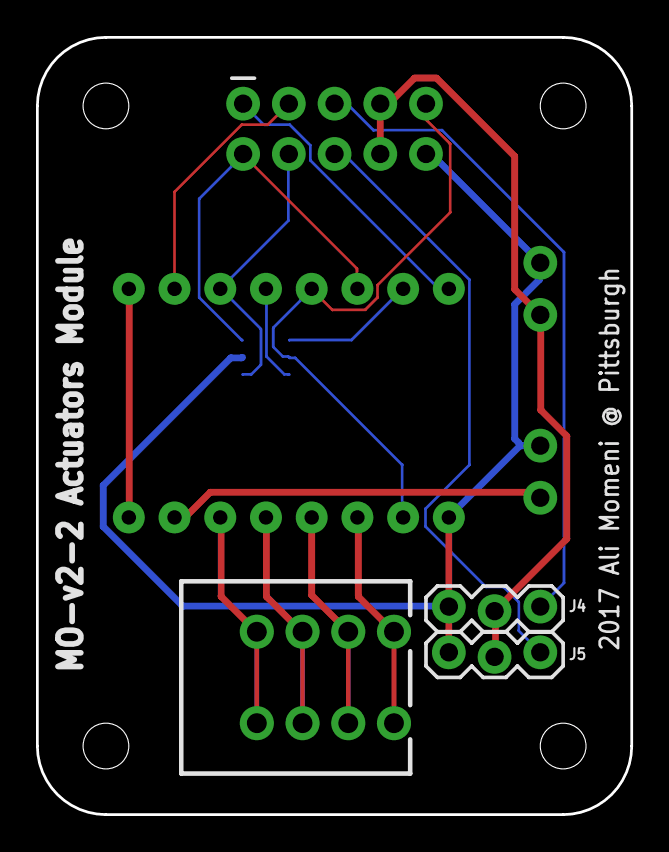
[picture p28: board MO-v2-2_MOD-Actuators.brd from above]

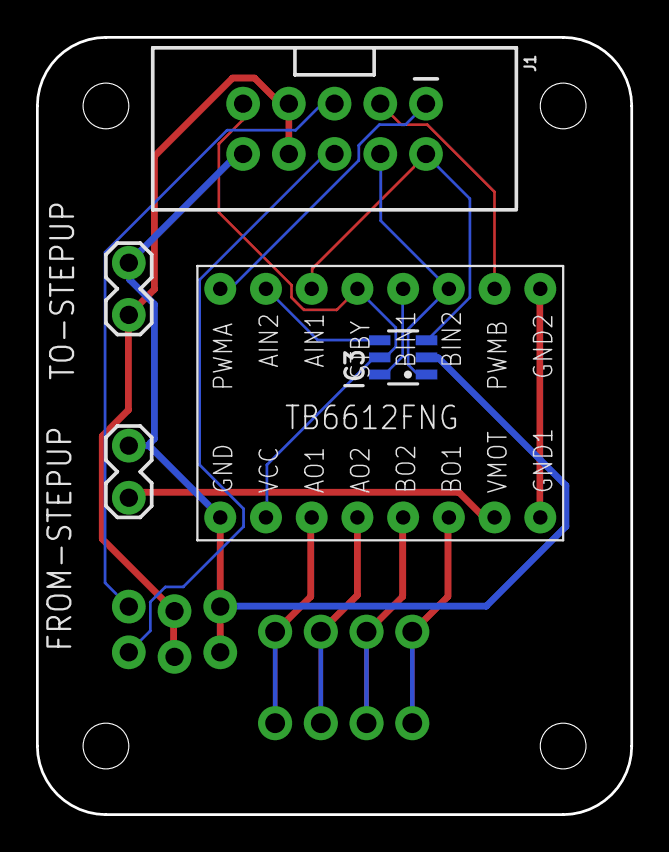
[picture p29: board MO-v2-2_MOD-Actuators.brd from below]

Board: 2 copper layers, 33.0 x 43.2 mm, 8 parts (5 on the bottom side), 17 nets.

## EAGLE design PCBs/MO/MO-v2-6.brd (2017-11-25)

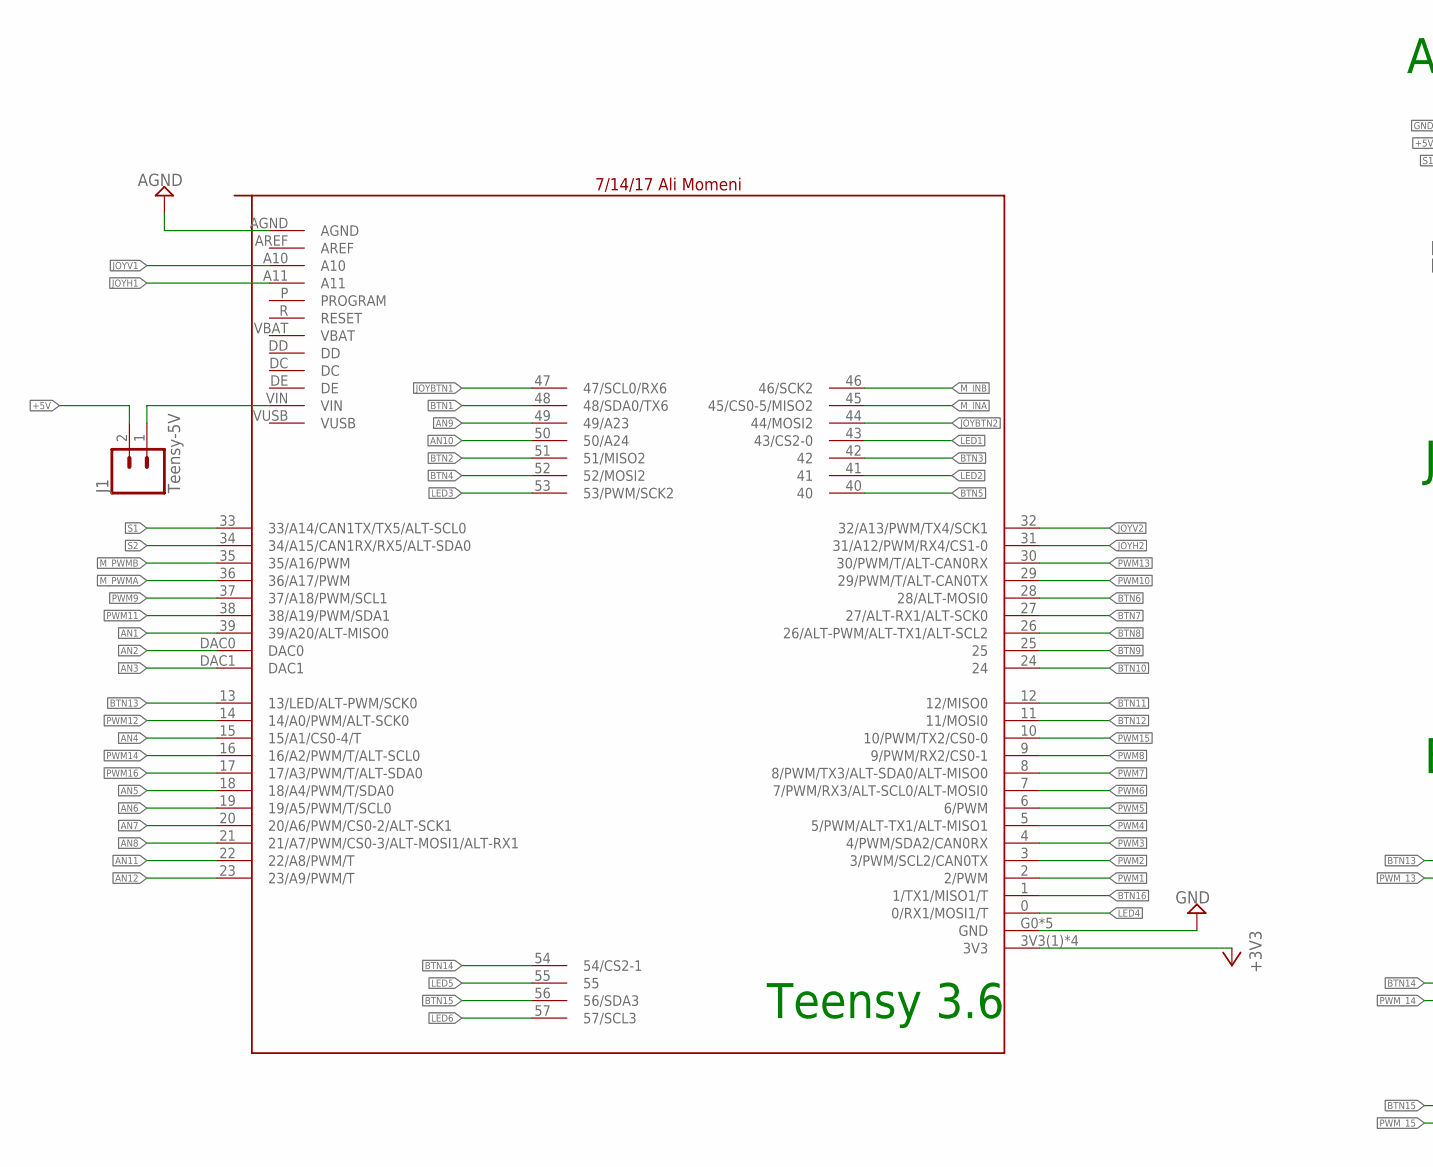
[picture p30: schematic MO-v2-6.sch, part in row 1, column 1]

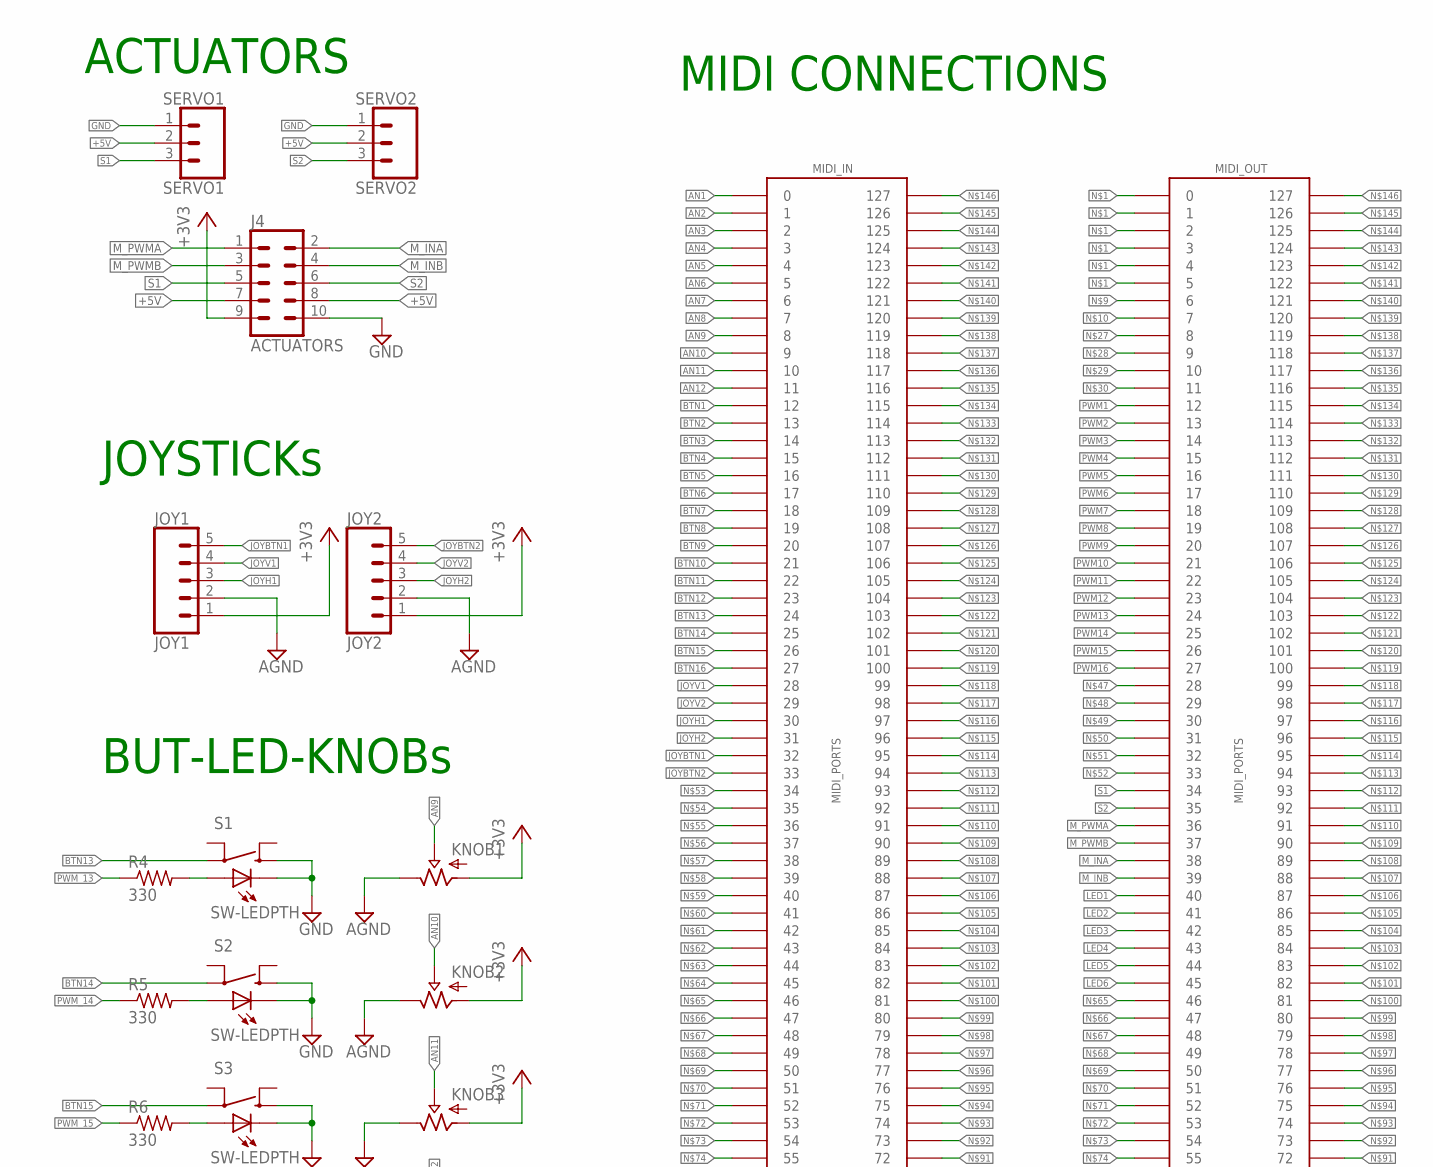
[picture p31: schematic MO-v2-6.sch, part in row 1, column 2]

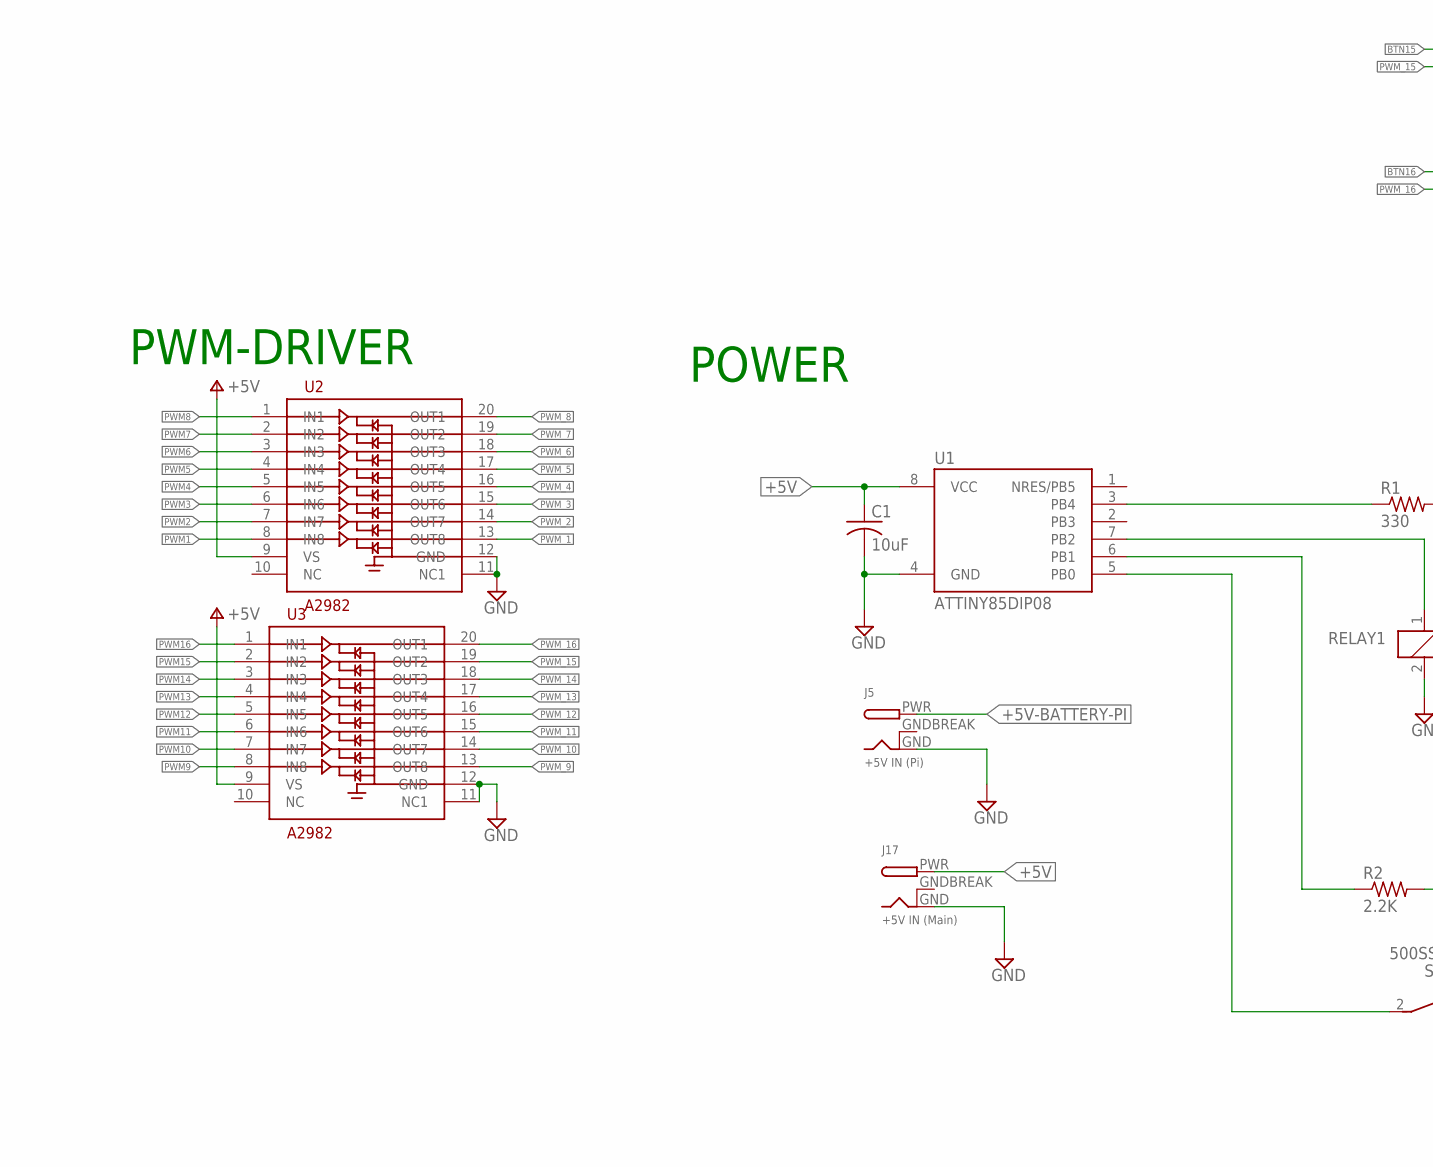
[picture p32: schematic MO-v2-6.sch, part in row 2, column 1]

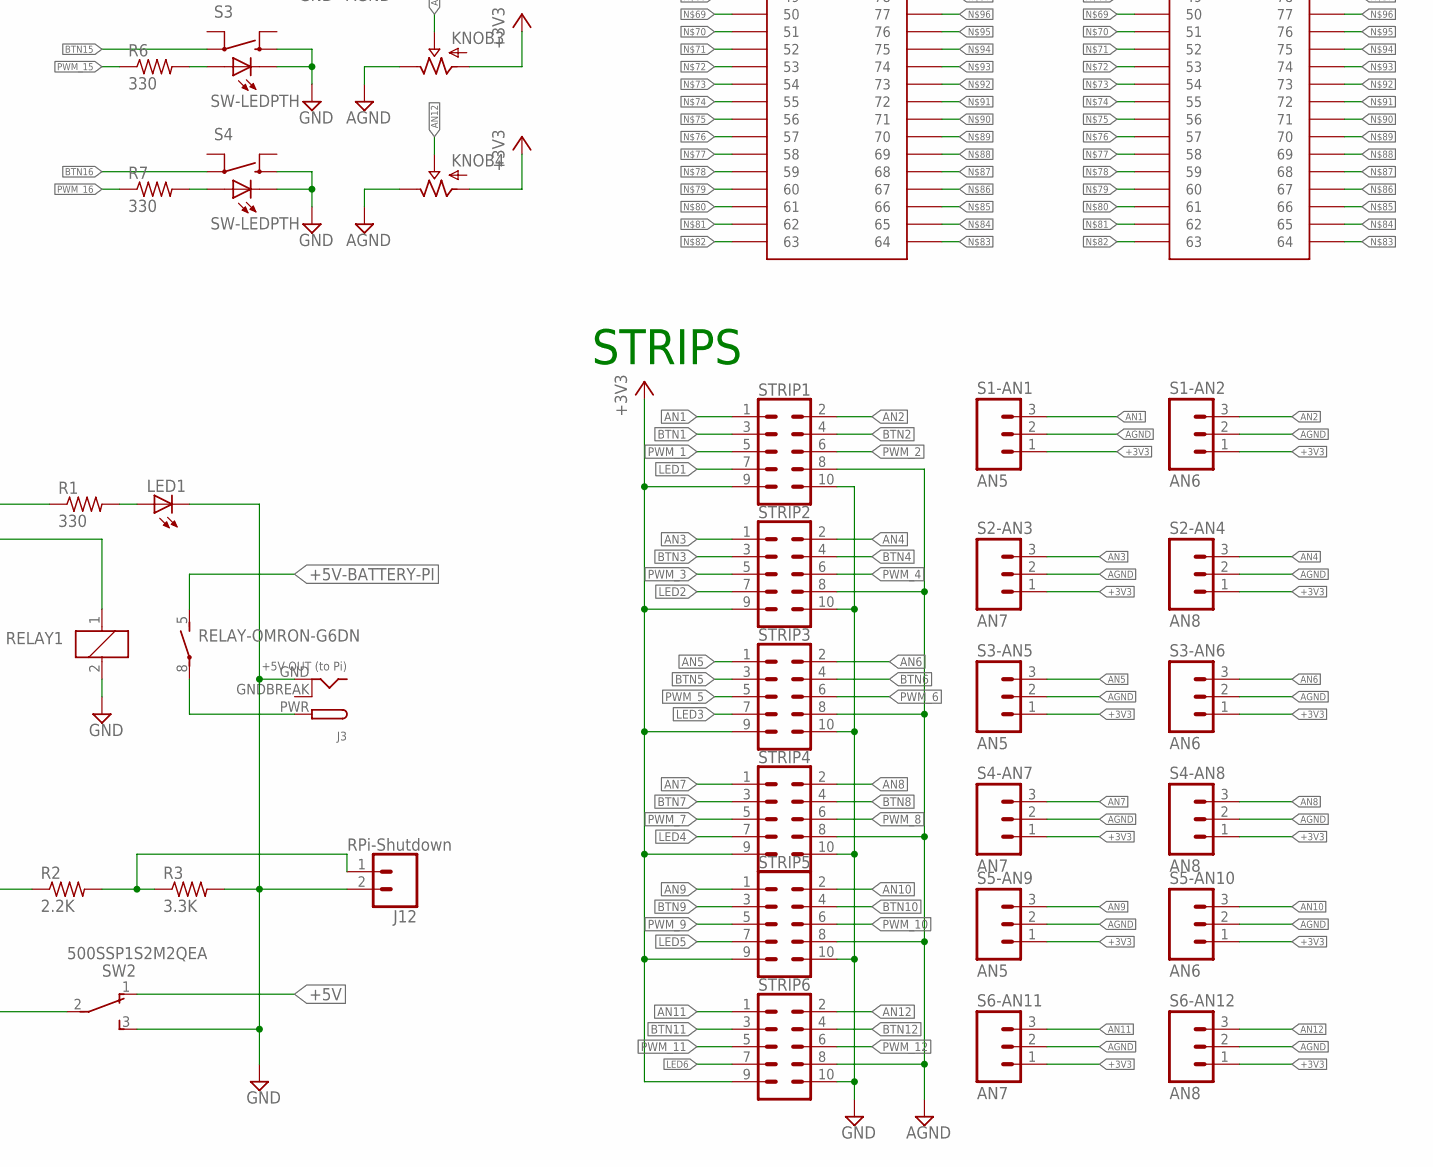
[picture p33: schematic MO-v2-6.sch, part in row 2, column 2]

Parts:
C1: 10uF; C050-024X044
J1: Teensy-5V; 1X02_LOCK
J3: +5V OUT (to Pi); DCJACK_2MM_PTH
J4: ACTUATORS; 2X5-SHROUDED_LOCK
J5: +5V IN (Pi); DCJACK_2MM_PTH
J12: RPi-Shutdown; 1X02_LOCK
J17: +5V IN (Main); DCJACK_2MM_PTH
JOY1: JOY1; 1X05_LOCK
JOY2: JOY2; 1X05_LOCK
KNOB1, KNOB2, KNOB3, KNOB4: POTALPHA_RD901; POT_ALPHA_RD901F-40-(L)R1
LED1: LED3MM
R1, R4, R5, R6, R7: 330; 0204/7
R2: 2.2K; 0204/7
R3: 3.3K; 0204/7
RELAY1: RELAY-OMRON-G6DN; G6DN-1A
S1, S2, S3, S4: SW-LEDPTH; SWITCH_TR2-MOMENTARY-LED
S1-AN1, S3-AN5, S5-AN9: AN5; 1X03_LOCK
S1-AN2, S3-AN6, S5-AN10: AN6; 1X03_LOCK
S2-AN3, S4-AN7, S6-AN11: AN7; 1X03_LOCK
S2-AN4, S4-AN8, S6-AN12: AN8; 1X03_LOCK
SERVO1: SERVO1; 1X03_LOCK@1
SERVO2: SERVO2; 1X03_LOCK@1
STRIP1, STRIP2, STRIP3, STRIP4, STRIP5, STRIP6: CONN_05X2SHD_LOCK; 2X5-SHROUDED_LOCK
SW2: 500SSP1S2M2QEA; SWITCH_SPDT_500SSP1S2M2QEA
TEENSY: TEENSY3_6-ALI_NO-USB-HOST; TEENSY3-6_NO-USB-HOST
U1: ATTINY85DIP08; DIP08
U2, U3: A2982; SOIC20

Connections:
+3V3: J4.9, JOY1.1, JOY2.1, KNOB1.1 (IN), KNOB2.1 (IN), KNOB3.1 (IN), KNOB4.1 (IN), S1-AN1.1, S1-AN2.1, S2-AN3.1, S2-AN4.1, S3-AN5.1, S3-AN6.1, S4-AN7.1, S4-AN8.1, S5-AN9.1, S5-AN10.1, S6-AN11.1, S6-AN12.1, STRIP1.9, STRIP2.9, STRIP3.9, STRIP4.9, STRIP5.9, STRIP6.9, TEENSY.3V3(1) (3V3), TEENSY.3V3(2) (3V3), TEENSY.3V3(3) (3V3), TEENSY.3V3(4) (3V3)
+5V: C1.1, J1.2, J4.7, J4.8, J17.PWR, SERVO1.2, SERVO2.2, SW2.1, U1.8 (VCC), U2.9 (VS), U3.9 (VS)
+5V-BATTERY-PI: J5.PWR, RELAY1.5
AGND: JOY1.2, JOY2.2, KNOB1.3 (OUT), KNOB2.3 (OUT), KNOB3.3 (OUT), KNOB4.3 (OUT), S1-AN1.2, S1-AN2.2, S2-AN3.2, S2-AN4.2, S3-AN5.2, S3-AN6.2, S4-AN7.2, S4-AN8.2, S5-AN9.2, S5-AN10.2, S6-AN11.2, S6-AN12.2, STRIP1.8, STRIP2.8, STRIP3.8, STRIP4.8, STRIP5.8, STRIP6.8, TEENSY.AGND
AN1: S1-AN1.3, STRIP1.1, TEENSY.39 (39/A20/ALT-MISO0)
AN2: S1-AN2.3, STRIP1.2, TEENSY.DAC0
AN3: S2-AN3.3, STRIP2.1, TEENSY.DAC1
AN4: S2-AN4.3, STRIP2.2, TEENSY.15 (15/A1/CS0-4/T)
AN5: S3-AN5.3, STRIP3.1, TEENSY.18 (18/A4/PWM/T/SDA0)
AN6: S3-AN6.3, STRIP3.2, TEENSY.19 (19/A5/PWM/T/SCL0)
AN7: S4-AN7.3, STRIP4.1, TEENSY.20 (20/A6/PWM/CS0-2/ALT-SCK1)
AN8: S4-AN8.3, STRIP4.2, TEENSY.21 (21/A7/PWM/CS0-3/ALT-MOSI1/ALT-RX1)
AN9: KNOB1.2 (WIPER), S5-AN9.3, STRIP5.1, TEENSY.49 (49/A23)
AN10: KNOB2.2 (WIPER), S5-AN10.3, STRIP5.2, TEENSY.50 (50/A24)
AN11: KNOB3.2 (WIPER), S6-AN11.3, STRIP6.1, TEENSY.22 (22/A8/PWM/T)
AN12: KNOB4.2 (WIPER), S6-AN12.3, STRIP6.2, TEENSY.23 (23/A9/PWM/T)
BTN1: STRIP1.3, TEENSY.48 (48/SDA0/TX6)
BTN2: STRIP1.4, TEENSY.51 (51/MISO2)
BTN3: STRIP2.3, TEENSY.42
BTN4: STRIP2.4, TEENSY.52 (52/MOSI2)
BTN5: STRIP3.3, TEENSY.40
BTN6: STRIP3.4, TEENSY.28 (28/ALT-MOSI0)
BTN7: STRIP4.3, TEENSY.27 (27/ALT-RX1/ALT-SCK0)
BTN8: STRIP4.4, TEENSY.26 (26/ALT-PWM/ALT-TX1/ALT-SCL2)
BTN9: STRIP5.3, TEENSY.25
BTN10: STRIP5.4, TEENSY.24
BTN11: STRIP6.3, TEENSY.12 (12/MISO0)
BTN12: STRIP6.4, TEENSY.11 (11/MOSI0)
BTN13: S1.3, TEENSY.13 (13/LED/ALT-PWM/SCK0)
BTN14: S2.3, TEENSY.54 (54/CS2-1)
BTN15: S3.3, TEENSY.56 (56/SDA3)
BTN16: S4.3, TEENSY.1 (1/TX1/MISO1/T)
GND: C1.2, J3.GND, J4.10, J5.GND, J12.2, J17.GND, LED1.K (C), R3.2, RELAY1.2, S1.1, S1.C, S2.1, S2.C, S3.1, S3.C, S4.1, S4.C, SERVO1.1, SERVO2.1, STRIP1.10, STRIP2.10, STRIP3.10, STRIP4.10, STRIP5.10, STRIP6.10, SW2.3, TEENSY.G0 (GND), TEENSY.G1 (GND), TEENSY.G2 (GND), TEENSY.G3 (GND), TEENSY.G6 (GND), U1.4 (GND), U2.11 (NC1), U2.12 (GND), U3.11 (NC1), U3.12 (GND)
GNDBREAK: J3.GNDBREAK, J5.GNDBREAK, J17.GNDBREAK
JOYBTN1: JOY1.5, TEENSY.47 (47/SCL0/RX6)
JOYBTN2: JOY2.5, TEENSY.44 (44/MOSI2)
JOYH1: JOY1.3, TEENSY.A11
JOYH2: JOY2.3, TEENSY.31 (31/A12/PWM/RX4/CS1-0)
JOYV1: JOY1.4, TEENSY.A10
JOYV2: JOY2.4, TEENSY.32 (32/A13/PWM/TX4/SCK1)
LED1: STRIP1.7, TEENSY.43 (43/CS2-0)
LED2: STRIP2.7, TEENSY.41
LED3: STRIP3.7, TEENSY.53 (53/PWM/SCK2)
LED4: STRIP4.7, TEENSY.0 (0/RX1/MOSI1/T)
LED5: STRIP5.7, TEENSY.55
LED6: STRIP6.7, TEENSY.57 (57/SCL3)
M_INA: J4.2, TEENSY.45 (45/CS0-5/MISO2)
M_INB: J4.4, TEENSY.46 (46/SCK2)
M_PWMA: J4.1, TEENSY.36 (36/A17/PWM)
M_PWMB: J4.3, TEENSY.35 (35/A16/PWM)
unnamed: LED1.A, R1.2
unnamed: R4.2, S1.A
unnamed: R5.2, S2.A
unnamed: J12.1, R2.2, R3.1
unnamed: R6.2, S3.A
unnamed: J1.1, TEENSY.VIN
unnamed: R7.2, S4.A
PI-REST: R2.1, U1.6 (PB1)
PWM1: TEENSY.2 (2/PWM), U2.8 (IN8)
PWM2: TEENSY.3 (3/PWM/SCL2/CAN0TX), U2.7 (IN7)
PWM3: TEENSY.4 (4/PWM/SDA2/CAN0RX), U2.6 (IN6)
PWM4: TEENSY.5 (5/PWM/ALT-TX1/ALT-MISO1), U2.5 (IN5)
PWM5: TEENSY.6 (6/PWM), U2.4 (IN4)
PWM6: TEENSY.7 (7/PWM/RX3/ALT-SCL0/ALT-MOSI0), U2.3 (IN3)
PWM7: TEENSY.8 (8/PWM/TX3/ALT-SDA0/ALT-MISO0), U2.2 (IN2)
PWM8: TEENSY.9 (9/PWM/RX2/CS0-1), U2.1 (IN1)
PWM9: TEENSY.37 (37/A18/PWM/SCL1), U3.8 (IN8)
PWM10: TEENSY.29 (29/PWM/T/ALT-CAN0TX), U3.7 (IN7)
PWM11: TEENSY.38 (38/A19/PWM/SDA1), U3.6 (IN6)
PWM12: TEENSY.14 (14/A0/PWM/ALT-SCK0), U3.5 (IN5)
PWM13: TEENSY.30 (30/PWM/T/ALT-CAN0RX), U3.4 (IN4)
PWM14: TEENSY.16 (16/A2/PWM/T/ALT-SCL0), U3.3 (IN3)
PWM15: TEENSY.10 (10/PWM/TX2/CS0-0), U3.2 (IN2)
PWM16: TEENSY.17 (17/A3/PWM/T/ALT-SDA0), U3.1 (IN1)
PWM_1: STRIP1.5, U2.13 (OUT8)
PWM_2: STRIP1.6, U2.14 (OUT7)
PWM_3: STRIP2.5, U2.15 (OUT6)
PWM_4: STRIP2.6, U2.16 (OUT5)
PWM_5: STRIP3.5, U2.17 (OUT4)
PWM_6: STRIP3.6, U2.18 (OUT3)
PWM_7: STRIP4.5, U2.19 (OUT2)
PWM_8: STRIP4.6, U2.20 (OUT1)
PWM_9: STRIP5.5, U3.13 (OUT8)
PWM_10: STRIP5.6, U3.14 (OUT7)
PWM_11: STRIP6.5, U3.15 (OUT6)
PWM_12: STRIP6.6, U3.16 (OUT5)
PWM_13: R4.1, U3.17 (OUT4)
PWM_14: R5.1, U3.18 (OUT3)
PWM_15: R6.1, U3.19 (OUT2)
PWM_16: R7.1, U3.20 (OUT1)
RELAY-PWR: J3.PWR, RELAY1.8
S1: J4.5, SERVO1.3, TEENSY.33 (33/A14/CAN1TX/TX5/ALT-SCL0)
S2: J4.6, SERVO2.3, TEENSY.34 (34/A15/CAN1RX/RX5/ALT-SDA0)
TINY_LED: R1.1, U1.3 (PB4)
TINY_RELAY: RELAY1.1, U1.7 (PB2)
TINY_SWITCH: SW2.2, U1.5 (PB0)

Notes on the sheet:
BUT-LED-KNOBs
JOYSTICKs
PWM-DRIVER
STRIPS
ACTUATORS
POWER
Teensy 3.6
MIDI CONNECTIONS

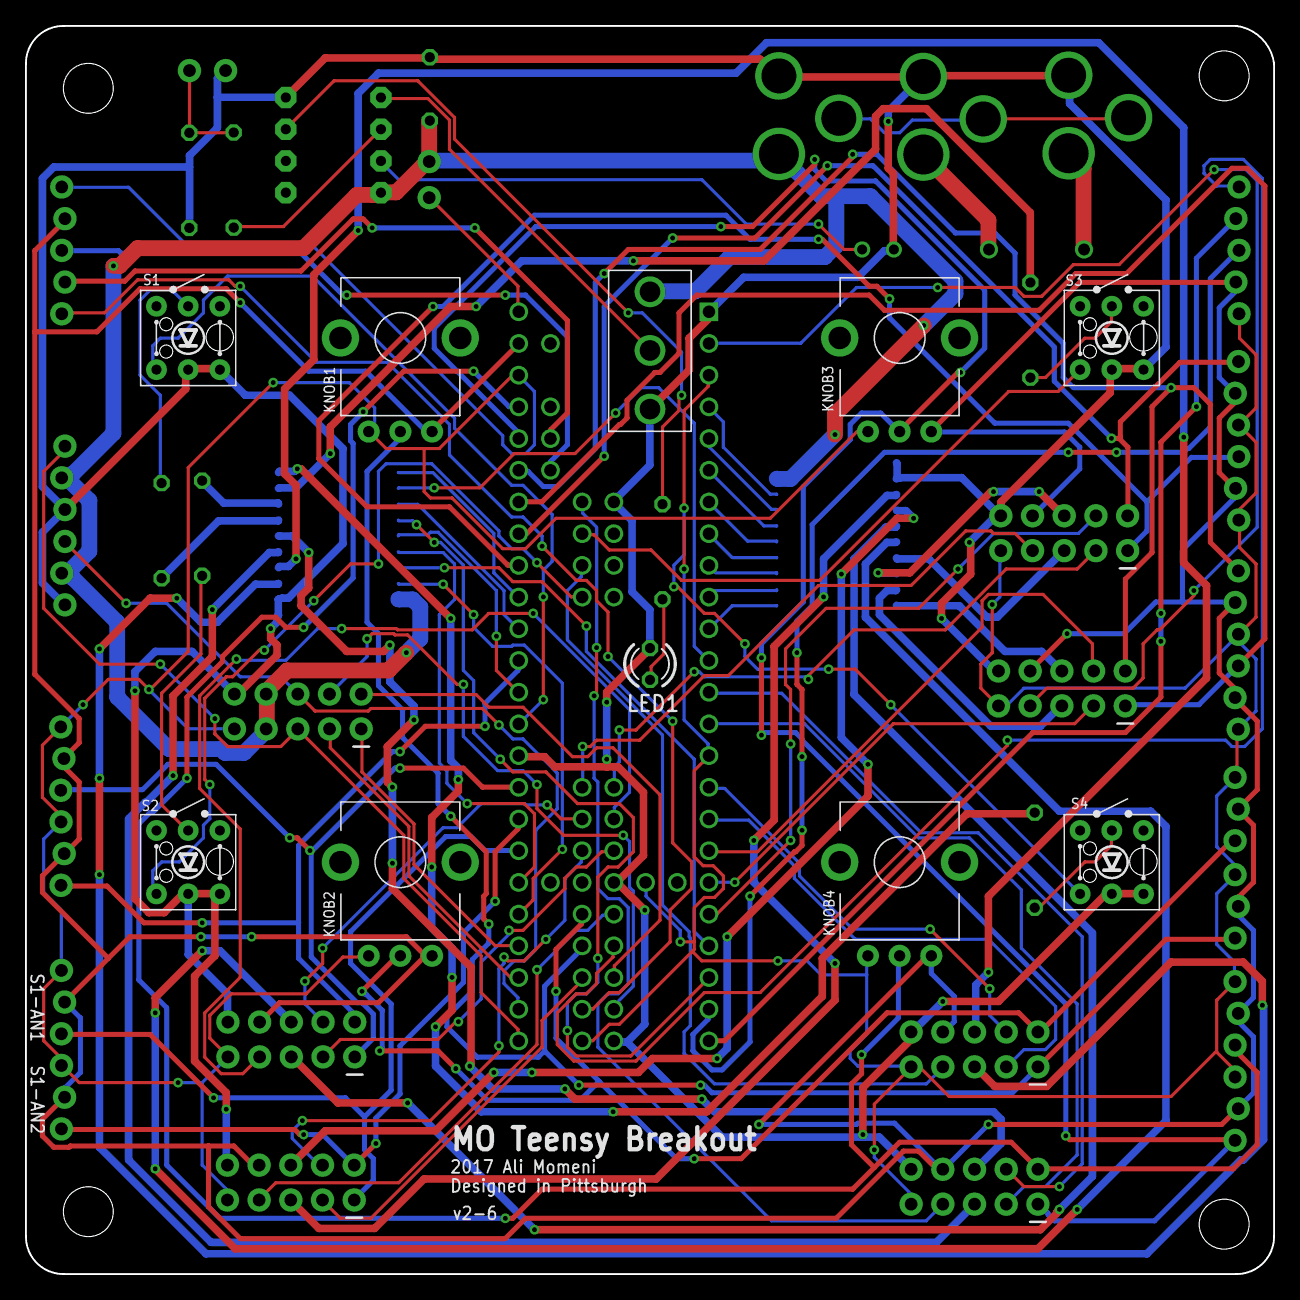
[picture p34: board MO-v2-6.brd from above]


Board: 2 copper layers, 100.0 x 100.0 mm, 51 parts (41 on the bottom side), 96 nets.

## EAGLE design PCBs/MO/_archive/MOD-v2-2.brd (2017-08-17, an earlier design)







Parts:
C1: 10uF; C0805
J1: SERVO1; 1X03_LOCK@1
J2: SERVO2; 1X03_LOCK@1
J3: RPi; DCJACK_2MM_PTH
J4: ACTUATORS; 2X5-SHROUDED_LOCK
J5: Battery; DCJACK_2MM_PTH
J6: AN5; 1X03_LOCK
J7: AN6; 1X03_LOCK
J8: AN7; 1X03_LOCK
J9: AN8; 1X03_LOCK
J10: JOY1; 1X05_LOCK
J11: JOY2; 1X05_LOCK
J12: RPi-Shutdown; 1X02_LOCK
KNOB1, KNOB2, KNOB3, KNOB4: TRIM; TRIM-PCB-9MM
LED1: LED3MM
R1: 330; M0805
R2: 2.2K; M0805
R3: 3.3K; M0805
RELAY1: RELAY-OMRON-G6DN; G6DN-1A
RN1, RN2: 2NBS16-8; SO16
S1, S2, S3, S4: SW-LEDPTH; SWITCH_TR2-MOMENTARY-LED
STRIP1, STRIP2, STRIP3, STRIP4, STRIP5, STRIP6: CONN_05X2SHD_LOCK; 2X5-SHROUDED_LOCK
SW2: 500SSP1S2M2QEA; SWITCH_SPDT_500SSP1S2M2QEA
TEENSY: TEENSY3_6-ALI_NO-USB-HOST; TEENSY3-6_NO-USB-HOST
U1: ATTINY85
U$1, U$2: A2982; SOIC20

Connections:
+3V3: J4.9, J6.1, J7.1, J8.1, J9.1, J10.1, J11.1, KNOB1.1 (A), KNOB2.1 (A), KNOB3.1 (A), KNOB4.1 (A), STRIP1.9, STRIP2.9, STRIP3.9, STRIP4.9, STRIP5.9, STRIP6.9, TEENSY.3V3(1) (3V3), TEENSY.3V3(2) (3V3), TEENSY.3V3(3) (3V3), TEENSY.3V3(4) (3V3)
+5V: J1.2, J2.2, J3.PWR, J4.7, J4.8, R1.1, RELAY1.8, U1.3 (PB4)
+5V-BATTERY: C1.1, J5.PWR, RELAY1.5, SW2.1, U1.8 (VCC)
AGND: J6.3, J7.3, J8.3, J9.3, J10.2, J11.2, KNOB1.3 (E), KNOB2.3 (E), KNOB3.3 (E), KNOB4.3 (E), STRIP1.8, STRIP2.8, STRIP3.8, STRIP4.8, STRIP5.8, STRIP6.8, TEENSY.AGND
AN1: STRIP1.1, TEENSY.39 (39/A20/ALT-MISO0)
AN2: STRIP1.2, TEENSY.DAC0
AN3: STRIP2.1, TEENSY.DAC1
AN4: STRIP2.2, TEENSY.15 (15/A1/CS0-4/T)
AN5: J6.2, STRIP3.1, TEENSY.18 (18/A4/PWM/T/SDA0)
AN6: J7.2, STRIP3.2, TEENSY.19 (19/A5/PWM/T/SCL0)
AN7: J8.2, STRIP4.1, TEENSY.20 (20/A6/PWM/CS0-2/ALT-SCK1)
AN8: J9.2, STRIP4.2, TEENSY.21 (21/A7/PWM/CS0-3/ALT-MOSI1/ALT-RX1)
AN9: KNOB1.2 (S), STRIP5.1, TEENSY.49 (49/A23)
AN10: KNOB2.2 (S), STRIP5.2, TEENSY.50 (50/A24)
AN11: KNOB3.2 (S), STRIP6.1, TEENSY.22 (22/A8/PWM/T)
AN12: KNOB4.2 (S), STRIP6.2, TEENSY.23 (23/A9/PWM/T)
B1: STRIP1.3, TEENSY.48 (48/SDA0/TX6)
B2: STRIP1.4, TEENSY.51 (51/MISO2)
B3: STRIP2.3, TEENSY.42
B4: STRIP2.4, TEENSY.52 (52/MOSI2)
B5: STRIP3.3, TEENSY.40
B6: STRIP3.4, TEENSY.28 (28/ALT-MOSI0)
B7: STRIP4.3, TEENSY.27 (27/ALT-RX1/ALT-SCK0)
B8: STRIP4.4, TEENSY.26 (26/ALT-PWM/ALT-TX1/ALT-SCL2)
B9: STRIP5.3, TEENSY.25
B10: STRIP5.4, TEENSY.24
B11: STRIP6.3, TEENSY.12 (12/MISO0)
B12: STRIP6.4, TEENSY.11 (11/MOSI0)
B13: S1.3, TEENSY.13 (13/LED/ALT-PWM/SCK0)
B14: S2.3, TEENSY.54 (54/CS2-1)
B15: S3.3, TEENSY.56 (56/SDA3)
B16: S4.3, TEENSY.1 (1/TX1/MISO1/T)
GND: C1.2, J1.1, J2.1, J3.GND, J4.10, J5.GND, J12.2, LED1.K (C), R3.2, RELAY1.2, S1.1, S1.C, S2.1, S2.C, S3.1, S3.C, S4.1, S4.C, STRIP1.10, STRIP2.10, STRIP3.10, STRIP4.10, STRIP5.10, STRIP6.10, SW2.3, TEENSY.G0 (GND), TEENSY.G1 (GND), TEENSY.G2 (GND), TEENSY.G3 (GND), TEENSY.G6 (GND), U1.4 (GND), U$1.12 (GND), U$2.12 (GND)
GNDBREAK: J3.GNDBREAK, J5.GNDBREAK
JOYB1: J10.5, TEENSY.47 (47/SCL0/RX6)
JOYB2: J11.5, TEENSY.44 (44/MOSI2)
JOYH1: J10.3, TEENSY.A11
JOYH2: J11.3, TEENSY.31 (31/A12/PWM/RX4/CS1-0)
JOYV1: J10.4, TEENSY.A10
JOYV2: J11.4, TEENSY.32 (32/A13/PWM/TX4/SCK1)
LED1: STRIP1.7, TEENSY.43 (43/CS2-0)
LED2: STRIP2.7, TEENSY.41
LED3: STRIP3.7, TEENSY.53 (53/PWM/SCK2)
LED4: STRIP4.7, TEENSY.0 (0/RX1/MOSI1/T)
LED5: STRIP5.7, TEENSY.55
LED6: STRIP6.7, TEENSY.57 (57/SCL3)
M_INA: J4.2, TEENSY.45 (45/CS0-5/MISO2)
M_INB: J4.4, TEENSY.46 (46/SCK2)
M_PWMA: J4.1, TEENSY.36 (36/A17/PWM)
M_PWMB: J4.3, TEENSY.35 (35/A16/PWM)
unnamed: LED1.A, R1.2
unnamed: SW2.2, U1.5 (PB0)
unnamed: RELAY1.1, U1.7 (PB2)
unnamed: J12.1, R2.2, R3.1
unnamed: RN1.8, U$1.13 (OUT1)
unnamed: RN1.7, U$1.14 (OUT2)
unnamed: RN1.6, U$1.15 (OUT3)
unnamed: RN1.5, U$1.16 (OUT4)
unnamed: RN1.4, U$1.17 (OUT5)
unnamed: RN1.3, U$1.18 (OUT6)
unnamed: RN1.2, U$1.19 (OUT7)
unnamed: RN1.1, U$1.20 (OUT8)
unnamed: RN2.1, U$2.20 (OUT8)
unnamed: RN2.2, U$2.19 (OUT7)
unnamed: RN2.3, U$2.18 (OUT6)
unnamed: RN2.4, U$2.17 (OUT5)
unnamed: RN2.5, U$2.16 (OUT4)
unnamed: RN2.6, U$2.15 (OUT3)
unnamed: RN2.7, U$2.14 (OUT2)
unnamed: RN2.8, U$2.13 (OUT1)
PI-REST: R2.1, U1.6 (PB1)
PWM1: TEENSY.8 (8/PWM/TX3/ALT-SDA0/ALT-MISO0), U$1.7 (IN7)
PWM2: TEENSY.9 (9/PWM/RX2/CS0-1), U$1.8 (IN8)
PWM3: TEENSY.6 (6/PWM), U$1.5 (IN5)
PWM4: TEENSY.7 (7/PWM/RX3/ALT-SCL0/ALT-MOSI0), U$1.6 (IN6)
PWM5: TEENSY.4 (4/PWM/SDA2/CAN0RX), U$1.4 (IN4)
PWM6: TEENSY.5 (5/PWM/ALT-TX1/ALT-MISO1), U$1.3 (IN3)
PWM7: TEENSY.2 (2/PWM), U$1.1 (IN1)
PWM8: TEENSY.3 (3/PWM/SCL2/CAN0TX), U$1.2 (IN2)
PWM9: TEENSY.17 (17/A3/PWM/T/ALT-SDA0), U$2.7 (IN7)
PWM10: TEENSY.10 (10/PWM/TX2/CS0-0), U$2.8 (IN8)
PWM11: TEENSY.16 (16/A2/PWM/T/ALT-SCL0), U$2.6 (IN6)
PWM12: TEENSY.14 (14/A0/PWM/ALT-SCK0), U$2.5 (IN5)
PWM13: TEENSY.30 (30/PWM/T/ALT-CAN0RX), U$2.4 (IN4)
PWM14: TEENSY.29 (29/PWM/T/ALT-CAN0TX), U$2.3 (IN3)
PWM15: TEENSY.38 (38/A19/PWM/SDA1), U$2.2 (IN2)
PWM16: TEENSY.37 (37/A18/PWM/SCL1), U$2.1 (IN1)
PWM_1: RN2.9, STRIP1.5
PWM_2: RN2.10, STRIP1.6
PWM_3: RN2.11, STRIP2.5
PWM_4: RN2.12, STRIP2.6
PWM_5: RN2.13, STRIP3.5
PWM_6: RN2.14, STRIP3.6
PWM_7: RN2.15, STRIP4.5
PWM_8: RN2.16, STRIP4.6
PWM_9: RN1.9, STRIP5.5
PWM_10: RN1.10, STRIP5.6
PWM_11: RN1.12, STRIP6.5
PWM_12: RN1.11, STRIP6.6
PWM_13: RN1.13, S1.A
PWM_14: RN1.14, S2.A
PWM_15: RN1.15, S3.A
PWM_16: RN1.16, S4.A
S1: J1.3, J4.5, TEENSY.33 (33/A14/CAN1TX/TX5/ALT-SCL0)
S2: J2.3, J4.6, TEENSY.34 (34/A15/CAN1RX/RX5/ALT-SDA0)
V+: U$1.9 (VS), U$2.9 (VS)

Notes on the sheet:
BUT-LED-KNOBs
JOYSTICKs
PWM-DRIVER
STRIPS
ACTUATORS
POWER
Teensy 3.6
MIDI CONNECTIONS

Board: 2 copper layers, 39 parts (18 on the bottom side), 106 nets, no tracks yet.

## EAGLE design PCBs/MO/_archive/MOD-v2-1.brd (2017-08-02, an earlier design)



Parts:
IC1, IC2: ULN2803; DIL18
J1: SERVO1; 1X03_LOCK@1
J2: SERVO2; 1X03_LOCK@1
J3: STRIPS; 2X30_SHROUDED
J4: ACTUATORS; 2X5-SHROUDED_LOCK
J5: POWER-5V; DCJACK_2MM_PTH
J6: AN-IN-1; 1X03_NO_SILK
J7: AN-IN-2; 1X03_NO_SILK
J8: AN-IN-3; 1X03_NO_SILK
J9: AN-IN-4; 1X03_NO_SILK
J10: JOY1; 1X05_LOCK
J11: JOY2; 1X05_LOCK
KNOB1, KNOB2, KNOB3, KNOB4: TRIM; TRIM-PCB-9MM
LED1: LED3MM
R1: 330; 0204/7
RN1, RN2: 330; RESISTOR-NET-8P-DIL16
S5, S6, S7, S8: SW-LEDPTH; TR2-SWITCH-MOMENTARY-LED
SW1: 500SSP1S2M2QEA; SWITCH_SPDT_500SSP1S2M2QEA
TEENSY: TEENSY3_6-ALI_NO-USB-HOST; TEENSY3-6_NO-USB-HOST

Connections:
+3V3: J3.9, J3.19, J3.29, J3.39, J3.49, J3.59, J4.9, J6.1, J7.1, J8.1, J9.1, J10.1, J11.1, KNOB1.1 (A), KNOB2.1 (A), KNOB3.1 (A), KNOB4.1 (A), TEENSY.3V3(1) (3V3), TEENSY.3V3(2) (3V3), TEENSY.3V3(3) (3V3), TEENSY.3V3(4) (3V3)
+5V: IC1.10 (CD+), IC2.10 (CD+), J1.2, J2.2, J4.7, J4.8, R1.2, SW1.1
AGND: J3.8, J3.18, J3.28, J3.38, J3.48, J3.58, J6.3, J7.3, J8.3, J9.3, J10.2, J11.2, KNOB1.3 (E), KNOB2.3 (E), KNOB3.3 (E), KNOB4.3 (E), TEENSY.AGND
AN1: J3.1, TEENSY.22 (22/A8/PWM/T)
AN2: J3.2, TEENSY.23 (23/A9/PWM/T)
AN3: J3.11, TEENSY.20 (20/A6/PWM/CS0-2/ALT-SCK1)
AN4: J3.12, TEENSY.21 (21/A7/PWM/CS0-3/ALT-MOSI1/ALT-RX1)
AN5: J3.21, J6.2, TEENSY.19 (19/A5/PWM/T/SCL0)
AN6: J7.2, TEENSY.39 (39/A20/ALT-MISO0)
AN7: J3.31, J8.2, TEENSY.DAC0
AN8: J3.32, J9.2, TEENSY.15 (15/A1/CS0-4/T)
AN9: J3.44, KNOB1.2 (S), TEENSY.DAC1
AN10: J3.43, KNOB2.2 (S), TEENSY.18 (18/A4/PWM/T/SDA0)
AN11: J3.51, KNOB3.2 (S), TEENSY.50 (50/A24)
AN12: J3.52, KNOB4.2 (S), TEENSY.49 (49/A23)
BTN1: J3.3, TEENSY.54 (54/CS2-1)
BTN2: J3.4, TEENSY.56 (56/SDA3)
BTN3: J3.13, TEENSY.12 (12/MISO0)
BTN4: J3.14, TEENSY.24
BTN5: J3.23, TEENSY.1 (1/TX1/MISO1/T)
BTN6: TEENSY.11 (11/MOSI0)
BTN7: J3.33, TEENSY.26 (26/ALT-PWM/ALT-TX1/ALT-SCL2)
BTN8: J3.34, TEENSY.25
BTN9: J3.45, TEENSY.27 (27/ALT-RX1/ALT-SCK0)
BTN10: J3.42, TEENSY.40
BTN11: J3.53, TEENSY.52 (52/MOSI2)
BTN12: J3.54, TEENSY.48 (48/SDA0/TX6)
BTN13: S5.1, TEENSY.42
BTN14: S6.1, TEENSY.51 (51/MISO2)
BTN15: S7.1, TEENSY.28 (28/ALT-MOSI0)
BTN16: S8.1, TEENSY.13 (13/LED/ALT-PWM/SCK0)
GND: IC1.9 (GND), IC2.9 (GND), J1.1, J2.1, J3.10, J3.20, J3.30, J3.40, J3.50, J3.60, J4.10, J5.GND, LED1.K (C), S5.3, S6.3, S7.3, S8.3, TEENSY.G0 (GND), TEENSY.G1 (GND), TEENSY.G2 (GND), TEENSY.G3 (GND), TEENSY.G6 (GND)
GNDBREAK: J5.GNDBREAK
JOYB1: J10.5, TEENSY.47 (47/SCL0/RX6)
JOYB2: J11.5, TEENSY.44 (44/MOSI2)
JOYH1: J10.3, TEENSY.A11
JOYH2: J11.3, TEENSY.31 (31/A12/PWM/RX4/CS1-0)
JOYV1: J10.4, TEENSY.A10
JOYV2: J11.4, TEENSY.32 (32/A13/PWM/TX4/SCK1)
LED1: J3.7, TEENSY.55
LED2: J3.17, TEENSY.57 (57/SCL3)
LED3: J3.27, TEENSY.0 (0/RX1/MOSI1/T)
LED4: J3.37, TEENSY.53 (53/PWM/SCK2)
LED5: J3.47, TEENSY.41
LED6: J3.57, TEENSY.43 (43/CS2-0)
M_INA: J4.2, TEENSY.45 (45/CS0-5/MISO2)
M_INB: J4.4, TEENSY.46 (46/SCK2)
M_PWMA: J4.1, TEENSY.36 (36/A17/PWM)
M_PWMB: J4.3, TEENSY.35 (35/A16/PWM)
unnamed: J5.PWR, SW1.2
unnamed: LED1.A, R1.1
unnamed: IC1.18 (O1), RN1.A1 (1)
unnamed: IC1.17 (O2), RN1.B1 (1)
unnamed: IC1.16 (O3), RN1.C1 (1)
unnamed: IC1.15 (O4), RN1.D1 (1)
unnamed: IC1.14 (O5), RN1.E1 (1)
unnamed: IC1.13 (O6), RN1.F1 (1)
unnamed: IC1.12 (O7), RN1.G1 (1)
unnamed: IC1.11 (O8), RN1.H1 (1)
unnamed: IC2.18 (O1), RN2.A1 (1)
unnamed: IC2.17 (O2), RN2.B1 (1)
unnamed: IC2.16 (O3), RN2.C1 (1)
unnamed: IC2.15 (O4), RN2.D1 (1)
unnamed: IC2.14 (O5), RN2.E1 (1)
unnamed: IC2.12 (O7), RN2.G1 (1)
unnamed: IC2.11 (O8), RN2.H1 (1)
unnamed: IC2.13 (O6), RN2.F1 (1)
PWM1: IC1.7 (I7), TEENSY.3 (3/PWM/SCL2/CAN0TX)
PWM2: IC1.8 (I8), TEENSY.2 (2/PWM)
PWM3: IC1.5 (I5), TEENSY.5 (5/PWM/ALT-TX1/ALT-MISO1)
PWM4: IC1.6 (I6), TEENSY.4 (4/PWM/SDA2/CAN0RX)
PWM5: IC1.4 (I4), TEENSY.6 (6/PWM)
PWM6: IC1.3 (I3), TEENSY.7 (7/PWM/RX3/ALT-SCL0/ALT-MOSI0)
PWM7: IC1.1 (I1), TEENSY.9 (9/PWM/RX2/CS0-1)
PWM8: IC1.2 (I2), TEENSY.8 (8/PWM/TX3/ALT-SDA0/ALT-MISO0)
PWM9: IC2.7 (I7), TEENSY.10 (10/PWM/TX2/CS0-0)
PWM10: IC2.8 (I8), TEENSY.17 (17/A3/PWM/T/ALT-SDA0)
PWM11: IC2.6 (I6), TEENSY.16 (16/A2/PWM/T/ALT-SCL0)
PWM12: IC2.5 (I5), TEENSY.14 (14/A0/PWM/ALT-SCK0)
PWM13: IC2.4 (I4), TEENSY.29 (29/PWM/T/ALT-CAN0TX)
PWM14: IC2.3 (I3), TEENSY.30 (30/PWM/T/ALT-CAN0RX)
PWM15: IC2.2 (I2), TEENSY.38 (38/A19/PWM/SDA1)
PWM16: IC2.1 (I1), TEENSY.37 (37/A18/PWM/SCL1)
PWM_1: J3.5, RN1.H2 (2)
PWM_2: J3.6, RN1.G2 (2)
PWM_3: J3.15, RN1.F2 (2)
PWM_4: J3.16, RN1.E2 (2)
PWM_5: J3.25, RN1.D2 (2)
PWM_6: RN1.C2 (2)
PWM_7: J3.35, RN1.B2 (2)
PWM_8: J3.36, RN1.A2 (2)
PWM_9: J3.46, RN2.H2 (2)
PWM_10: J3.41, RN2.G2 (2)
PWM_11: J3.55, RN2.E2 (2)
PWM_12: J3.56, RN2.F2 (2)
PWM_13: RN2.D2 (2), S5.C
PWM_14: RN2.C2 (2), S6.C
PWM_15: RN2.B2 (2), S7.C
PWM_16: RN2.A2 (2), S8.C
S1: J1.3, J4.5, TEENSY.34 (34/A15/CAN1RX/RX5/ALT-SDA0)
S2: J2.3, J4.6, TEENSY.33 (33/A14/CAN1TX/TX5/ALT-SCL0)
V+: S5.A, S6.A, S7.A, S8.A

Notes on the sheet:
BUT-LED-KNOBs
JOYSTICKs
PWM-DRIVER
STRIPS
ACTUATORS
POWER
Teensy 3.6
MIDI CONNECTIONS



Board: 2 copper layers, 141.0 x 53.3 mm, 27 parts (15 on the bottom side), 99 nets.

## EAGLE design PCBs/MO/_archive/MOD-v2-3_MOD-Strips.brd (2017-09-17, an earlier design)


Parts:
AN-IN-1, AN-IN-2: M031X03_NO_SILK; 1X03_NO_SILK
KNOB1, KNOB2: POTALPHA_RD901; POT_ALPHA_RD901F-40-(L)R1
LED1: LED3MM
R1, R2: 330; 0204/7
R4: 220; 0204/7
S1, S2: SW-LEDPTH; SWITCH_TR2-MOMENTARY-LED
STRIP-MOD: J1; 2X5-SHROUDED_LOCK

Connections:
+3V3: AN-IN-1.1, AN-IN-2.1, KNOB1.1 (IN), KNOB2.1 (IN), STRIP-MOD.9
AGND: AN-IN-1.3, AN-IN-2.3, KNOB1.3 (OUT), KNOB2.3 (OUT), STRIP-MOD.8
AN1: AN-IN-1.2, KNOB1.2 (WIPER), STRIP-MOD.1
AN2: AN-IN-2.2, KNOB2.2 (WIPER), STRIP-MOD.2
B1: S1.3, STRIP-MOD.3
B2: S2.3, STRIP-MOD.4
GND: LED1.K (C), S1.1, S1.C, S2.1, S2.C, STRIP-MOD.10
LED1: R4.1, STRIP-MOD.7
N1: LED1.A, R4.2
unnamed: R1.1, S1.A
unnamed: R2.1, S2.A
PWM_1: R1.2, STRIP-MOD.5
PWM_2: R2.2, STRIP-MOD.6

Board: 2 copper layers, 11 parts (6 on the bottom side), 13 nets, no tracks yet.

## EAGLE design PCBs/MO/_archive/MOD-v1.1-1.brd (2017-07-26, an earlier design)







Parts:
AN-HEAD-1, AN-HEAD-2, AN-HEAD-3, AN-HEAD-4: M031X03_NO_SILK; 1X03_NO_SILK
GND-SHRT: M02LOCK; 1X02_LOCK
I2C: M04LOCK; 1X04_LOCK
IC1, IC2: ULN2803; DIL18
IC3: SN74LVC2G04DBV; SOT23-6
J1: SERVO 1; 1X03_LOCK@1
J2: SERVO 2; 1X03_LOCK@1
J3: SERVO 3; 1X03_LOCK@1
JOY1, JOY2: CONN_05LOCK; 1X05_LOCK
MOTORS1: M04; SPRINGTERMINAL-2.54MM-4
POT1, POT2, POT3, POT4: TRIM; TRIM-PCB-9MM
POWER-5V: DCBARRELPTH; DCJACK_2MM_PTH
R5, R6: RESISTORPTH-1/6W; 1/6W-RES
RN1, RN2: 330; RESISTOR-NET-8P-DIL16
S1, S2, S3, S4: SW-LEDPTH; TR2-SWITCH-MOMENTARY-LED
TEENSY: TEENSY3_6--ALLPINS; T36
U$7: POLOLU_TB6612FNG
US1, US2, US3, US4: SW-LEDPTH; TR2-SWITCH-MOMENTARY-LED
VIN: M02LOCK; 1X02_LOCK
VOUT: M02LOCK; 1X02_LOCK

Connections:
+3V3: AN-HEAD-1.1, AN-HEAD-2.1, AN-HEAD-3.1, AN-HEAD-4.1, I2C.1, IC3.5 (VCC), JOY1.2, JOY2.2, POT1.1 (A), POT2.1 (A), POT3.1 (A), POT4.1 (A), R5.1, R6.1, TEENSY.3V3(1) (3V3), TEENSY.3V3(2) (3V3), TEENSY.3V3(3) (3V3), TEENSY.3V3(4) (3V3), U$7.STBY, U$7.VCC
+5V: IC1.10 (CD+), IC2.10 (CD+), J1.2, J2.2, J3.2, POWER-5V.PWR, VIN.1
AGND: AN-HEAD-1.3, AN-HEAD-2.3, AN-HEAD-3.3, AN-HEAD-4.3, JOY1.1, JOY2.1, POT1.3 (E), POT2.3 (E), POT3.3 (E), POT4.3 (E), TEENSY.AGND
AN1: AN-HEAD-1.2, POT1.2 (S), TEENSY.14 (14/A0/PWM/ALT-SCK0)
AN2: AN-HEAD-2.2, POT2.2 (S), TEENSY.15 (15/A1/CS0-4/T)
AN3: AN-HEAD-3.2, POT3.2 (S), TEENSY.16 (16/A2/PWM/T/ALT-SCL0)
AN4: AN-HEAD-4.2, POT4.2 (S), TEENSY.33 (33/A14/CAN1TX/TX5/ALT-SCL0)
AN5: TEENSY.34 (34/A15/CAN1RX/RX5/ALT-SDA0)
AN6: TEENSY.35 (35/A16/PWM)
AN7: TEENSY.36 (36/A17/PWM)
AN8: TEENSY.39 (39/A20/ALT-MISO0)
AN9: TEENSY.DAC0
AN10: TEENSY.DAC1
AN11: TEENSY.A10
AN12: TEENSY.A11
B1: S1.1, TEENSY.11 (11/MOSI0)
B2: S2.1, TEENSY.12 (12/MISO0)
B3: S3.1, TEENSY.24
B4: S4.1, TEENSY.25
B5: TEENSY.26 (26/ALT-PWM/ALT-TX1/ALT-SCL2)
B6: TEENSY.27 (27/ALT-RX1/ALT-SCK0)
B7: TEENSY.28 (28/ALT-MOSI0)
B8: TEENSY.42
B9: TEENSY.43 (43/CS2-0)
B10: TEENSY.44 (44/MOSI2)
B11: TEENSY.45 (45/CS0-5/MISO2)
B12: TEENSY.46 (46/SCK2)
GND: GND-SHRT.2, I2C.2, IC1.9 (GND), IC2.9 (GND), IC3.2 (GND), J1.1, J2.1, J3.1, S1.3, S2.3, S3.3, S4.3, TEENSY.G0 (GND), TEENSY.G1 (GND), TEENSY.G2 (GND), TEENSY.G3 (GND), TEENSY.G4 (GND), TEENSY.G5 (GND), TEENSY.G6 (GND), U$7.GND, US1.3, US2.3, US3.3, US4.3, VIN.2, VOUT.2
GNDBREAK: POWER-5V.GNDBREAK
GND_MOT: GND-SHRT.1, POWER-5V.GND, U$7.GND1, U$7.GND2
I2C_SCL: I2C.3, R5.2
I2C_SDA: I2C.4, R6.2
JOYB1: JOY1.5, TEENSY.1 (1/TX1/MISO1/T)
JOYB2: JOY2.5, TEENSY.0 (0/RX1/MOSI1/T)
JOYH1: JOY1.3, TEENSY.20 (20/A6/PWM/CS0-2/ALT-SCK1)
JOYH2: JOY2.3, TEENSY.18 (18/A4/PWM/T/SDA0)
JOYV1: JOY1.4, TEENSY.19 (19/A5/PWM/T/SCL0)
JOYV2: JOY2.4, TEENSY.17 (17/A3/PWM/T/ALT-SDA0)
L1: IC1.8 (I8), TEENSY.2 (2/PWM)
L2: IC1.7 (I7), TEENSY.3 (3/PWM/SCL2/CAN0TX)
L3: IC1.6 (I6), TEENSY.4 (4/PWM/SDA2/CAN0RX)
L4: IC1.5 (I5), TEENSY.5 (5/PWM/ALT-TX1/ALT-MISO1)
L5: IC1.4 (I4), TEENSY.6 (6/PWM)
L6: IC1.3 (I3), TEENSY.7 (7/PWM/RX3/ALT-SCL0/ALT-MOSI0)
L7: IC1.2 (I2), TEENSY.8 (8/PWM/TX3/ALT-SDA0/ALT-MISO0)
L8: IC1.1 (I1), TEENSY.23 (23/A9/PWM/T)
L9: IC2.8 (I8), TEENSY.29 (29/PWM/T/ALT-CAN0TX)
L10: IC2.7 (I7), TEENSY.30 (30/PWM/T/ALT-CAN0RX)
L11: IC2.6 (I6), TEENSY.31 (31/A12/PWM/RX4/CS1-0)
L12: IC2.5 (I5), TEENSY.32 (32/A13/PWM/TX4/SCK1)
LED1: RN1.H2 (2), S1.C
LED2: RN1.G2 (2), S2.C
LED3: RN1.F2 (2), S3.C
LED4: RN1.E2 (2), S4.C
LED5: RN1.D2 (2)
LED6: RN1.C2 (2)
LED7: RN1.B2 (2)
LED8: RN1.A2 (2)
LED9: RN2.H2 (2)
LED10: RN2.G2 (2)
LED11: RN2.F2 (2)
LED12: RN2.E2 (2)
M_AIN: IC3.3 (2A), TEENSY.40, U$7.AIN1
M_BIN: IC3.1 (1A), TEENSY.41, U$7.BIN2
M_PWMA: TEENSY.21 (21/A7/PWM/CS0-3/ALT-MOSI1/ALT-RX1), U$7.PWMA
M_PWMB: TEENSY.22 (22/A8/PWM/T), U$7.PWMB
unnamed: IC3.6 (1Y), U$7.BIN1
unnamed: IC3.4 (2Y), U$7.AIN2
unnamed: IC1.18 (O1), RN1.A1 (1)
unnamed: IC1.17 (O2), RN1.B1 (1)
unnamed: IC1.16 (O3), RN1.C1 (1)
unnamed: IC1.15 (O4), RN1.D1 (1)
unnamed: IC1.14 (O5), RN1.E1 (1)
unnamed: IC1.13 (O6), RN1.F1 (1)
unnamed: IC1.12 (O7), RN1.G1 (1)
unnamed: IC1.11 (O8), RN1.H1 (1)
unnamed: IC2.18 (O1), RN2.A1 (1)
unnamed: IC2.17 (O2), RN2.B1 (1)
unnamed: IC2.16 (O3), RN2.C1 (1)
unnamed: IC2.15 (O4), RN2.D1 (1)
unnamed: IC2.14 (O5), RN2.E1 (1)
unnamed: IC2.12 (O7), RN2.G1 (1)
unnamed: IC2.11 (O8), RN2.H1 (1)
unnamed: IC2.13 (O6), RN2.F1 (1)
unnamed: MOTORS1.P$1 (1), U$7.BO1
unnamed: MOTORS1.P$2 (2), U$7.BO2
unnamed: MOTORS1.P$3 (3), U$7.AO2
unnamed: MOTORS1.P$4 (4), U$7.AO1
RX6: TEENSY.47 (47/SCL0/RX6)
S1: J1.3, TEENSY.9 (9/PWM/RX2/CS0-1)
S2: J2.3, TEENSY.10 (10/PWM/TX2/CS0-0)
S3: J3.3, TEENSY.49 (49/A23/PWM)
TX6: TEENSY.48 (48/SDA0/TX6)
UB1: TEENSY.57 (57/SCL3), US1.1
UB2: TEENSY.56 (56/SDA3), US2.1
UB3: TEENSY.55, US3.1
UB4: TEENSY.54 (54/CS2-1), US4.1
UL1: IC2.4 (I4), TEENSY.53 (53/PWM/SCK2)
UL2: IC2.3 (I3), TEENSY.52 (52/MOSI2)
UL3: IC2.2 (I2), TEENSY.51 (51/MISO2)
UL4: IC2.1 (I1), TEENSY.50 (50/A24/PWM)
ULED1: RN2.D2 (2), US1.C
ULED2: RN2.C2 (2), US2.C
ULED3: RN2.B2 (2), US3.C
ULED4: RN2.A2 (2), US4.C
V+: S1.A, S2.A, S3.A, S4.A, US1.A, US2.A, US3.A, US4.A
VMOT: U$7.VMOT, VOUT.1

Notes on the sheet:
***should combine into an illuminated pushbutton: look at: Digikey: 563-1933-ND Cheaper than sparkfun, LED color is variable, and uses less current
KNOB+LED+BUTTON (we need 12 of these)
MOTOR-DRIVER+JOYSTICK (we need 1 of these)
***CHANGE to the beefier STEP-UP from Amazon: https://www.amazon.com/gp/product/B01KFH32YI/ref=oh_aui_detailpage_o01_s00?ie=UTF8&psc=1 This is better than the smaller one we found because it has a built in voltage meter
POWER
SERVO+JOYSTICK (we need 1 of these)
LED-DRIVERs
USER_LEDs USER_BUTTONs
I2C
TEENSY 3.6

Board: 2 copper layers, 36 parts (15 on the bottom side), 80 nets, no tracks yet.

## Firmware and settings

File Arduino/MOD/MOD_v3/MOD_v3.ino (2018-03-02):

//Change these values for debugging
#define NUM_SERVOS 2    //2
#define NUM_MOTORS 2    //2

const int channel = 1;

#include "MO.h"
#include "Arrays.h"
#include "MIDI.h"

#include "Shield.h"
#include "StripCollection.h"
#include "JoystickCollection.h"
#include "Strip.h"
#include "Sensor.h"
#include "Joystick.h"

#include <Servo.h>

Servo servo[NUM_SERVOS];

Shield shield;

Strip * strip1 = new Strip(0);
Strip * strip2 = new Strip(1);
Strip * strip3 = new Strip(2);

Joystick joy1(0);
Joystick joy2(1);

//Add Sensors
Sensor * ir = new Sensor(POTS[4], POTS_MIDI[4]);
Sensor * ir2 = new Sensor(POTS[5], POTS_MIDI[5]);


StripCollection strips;
JoystickCollection joysticks;

void setup() {

  usbMIDI.setHandleNoteOff(OnNoteOff); //OnNoteOff function below
  usbMIDI.setHandleNoteOn(OnNoteOn);  //OnNoteOn function below
  usbMIDI.setHandleControlChange(OnControlChange);


  for (int b = 0; b < NUM_SERVOS; b++) {
      servo[b].attach(SERVOS[b]);
  }

  joysticks.add( &joy1);
  joysticks.add( &joy2);

  joysticks.calibrate();

  //Add Each strip to strips collection
  strips.add(strip1);
  strips.add(strip2);
  strips.add(strip3);

  //Add additional sensors to shield
  //shield.add(ir);
  //shield.add(ir2);
}



void loop() {

  shield.update();
  strips.update();
  joysticks.update();

  usbMIDI.read();
}



void OnNoteOn(byte channel, byte note, byte velocity) {
  shield.light(note, velocity);
  strips.light(note, velocity);

  //INVERSE MOTOR DIRECTION
  for (int b = 0; b < NUM_MOTORS; b++) {
    if (note == MOTORINS_MIDI[b]) {
      digitalWrite(MOTORINS[b], velocity * 2); //Send 0|1 based on 0-127 range
    }
  }

}

void OnNoteOff(byte channel, byte note, byte velocity) {
  shield.light(note, 0);
  strips.light(note, 0);

  //INVERSE MOTOR DIRECTION
  for (int b = 0; b < NUM_MOTORS; b++) {
    if (note == MOTORINS_MIDI[b]) {
      analogWrite(MOTORINS[b], 0); //Send 0|1 based on 0-127 range
    }
  }
}

void OnControlChange(byte channel, byte number, byte value) {
  //SERVO CONTROL
  for (int b = 0; b < NUM_SERVOS; b++) {
    if (number == SERVOS_MIDI[b]) {
      int val = map(value, 0, 127, 0, 180);
      servo[b].write(val);
    }
  }
  //MOTOR SPEED
  for (int b = 0; b < NUM_MOTORS; b++) {
    if (number == MOTORPWMS_MIDI[b]) {
      analogWrite(MOTORPWMS[b], value * 2);
    }
  }

}

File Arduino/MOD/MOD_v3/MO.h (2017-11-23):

//------------------------------------------------------
//Thiis file is automatically generated with pinlister.py
//------------------------------------------------------

const int LED4      = 0;
const int BTN16     = 1;
const int PWM1      = 2;
const int PWM2      = 3;
const int PWM3      = 4;
const int PWM4      = 5;
const int PWM5      = 6;
const int PWM6      = 7;
const int PWM7      = 8;
const int PWM8      = 9;
const int PWM15     = 10;
const int BTN12     = 11;
const int BTN11     = 12;
const int BTN13     = 13;
const int PWM12     = 14;
const int AN4       = 15;
const int PWM14     = 16;
const int PWM16     = 17;
const int AN5       = 18;
const int AN6       = 19;
const int AN7       = 20;
const int AN8       = 21;
const int AN11      = 22;
const int AN12      = 23;
const int BTN10     = 24;
const int BTN9      = 25;
const int BTN8      = 26;
const int BTN7      = 27;
const int BTN6      = 28;
const int PWM10     = 29;
const int PWM13     = 30;
const int JOYH2     = 31;
const int JOYV2     = 32;
const int S1        = 33;
const int S2        = 34;
const int M_PWMB    = 35;
const int M_PWMA    = 36;
const int PWM9      = 37;
const int PWM11     = 38;
const int AN1       = 39;
const int BTN5      = 40;
const int LED2      = 41;
const int BTN3      = 42;
const int LED1      = 43;
const int JOYBTN2   = 44;
const int M_INA     = 45;
const int M_INB     = 46;
const int JOYBTN1   = 47;
const int BTN1      = 48;
const int AN9       = 49;
const int AN10      = 50;
const int BTN2      = 51;
const int BTN4      = 52;
const int LED3      = 53;
const int BTN14     = 54;
const int LED5      = 55;
const int BTN15     = 56;
const int LED6      = 57;
const int JOYV1     = A10;
const int JOYH1     = A11;
const int AN2       = A21;
const int AN3       = A22;

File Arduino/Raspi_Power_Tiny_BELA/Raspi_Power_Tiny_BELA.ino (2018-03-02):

#include <Bounce2.h>

#define SHUDOWN_SIG 1     //Pin 6
#define PI_POWER 2        //Pin 7
#define SWITCH 0          //Pin 5
#define POWER_LED 4       //Pin 9

// Instantiate a Bounce object
Bounce debouncer = Bounce();

boolean ShutDown = true;

void setup() {
  // Setup the button with an internal pull-up :
  pinMode(SWITCH, INPUT_PULLUP);

  // After setting up the button, setup the Bounce instance :
  debouncer.attach(SWITCH);
  debouncer.interval(5); // interval in ms

  pinMode(PI_POWER, OUTPUT);
  pinMode(SHUDOWN_SIG, OUTPUT);
  pinMode(POWER_LED, OUTPUT);
}

void loop() {
  // Update the Bounce instance :
  debouncer.update();
  // Get the updated value :
  int value = debouncer.read();
  // Turn on or off the Relay as determined by the state of the SWITCH :
  if ( value == HIGH ) {
    if (ShutDown == false) ShutDown = true; // reset ShutDown bool
    digitalWrite(PI_POWER, HIGH );  // Keep the relay open
    digitalWrite(POWER_LED, HIGH);
    digitalWrite(SHUDOWN_SIG, HIGH);   //  Don't send the trigger signal to Pi
  }
  else {
    if (ShutDown) {
      digitalWrite(SHUDOWN_SIG, LOW);  //Trigger Pi's Python script to shutdown
      analogWrite(POWER_LED, 100);
      delay(8000);                    // Wait x amount of time so Pi properly shuts down
      analogWrite(POWER_LED, LOW);
      digitalWrite(PI_POWER, LOW );   //Close relay
      ShutDown = false;
    }
  }
}

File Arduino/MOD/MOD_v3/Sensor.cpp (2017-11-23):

#include "Sensor.h"

Sensor::Sensor()
{

}

Sensor::Sensor(const int _input, const int _midiAddress)
{
  input = _input;
  midiAddress = _midiAddress;
}


void Sensor::set(int _input, int _midiAddress) {
  input = _input;
  midiAddress = _midiAddress;
}

void Sensor::setInput(int _input) {
  input = _input;
}

void Sensor::setMidi(int _midiAddress) {
  midiAddress = _midiAddress;
}

void Sensor::update() {
  read();
  send();
}

void Sensor::read()
{
  if (timer >= 20) {
    current = analogRead(input) >> 3;
    
    current = (current + potPrev[0] + potPrev[1] + potPrev[2]) / 4;
    if (current != potAvg) {
      dataChange = true;
      potAvg = (current + potPrev[0] + potPrev[1] + potPrev[2]) / 4;
      potPrev[2] = potPrev[1];
      potPrev[1] = potPrev[0];
      potPrev[0] = analogRead(input) >> 3;
    }
    timer = 0;
  }
}

void Sensor::send(){
  if(dataChange){
    usbMIDI.sendControlChange(midiAddress, 127 - current, 1);
    dataChange = false;
    }
  }


int Sensor::getCurrent(){
  return current;
  }

int Sensor::getMidiAddress(){
  return midiAddress;
  }

void Sensor::setName(String _name) {
  name = _name;
}

void Sensor::debug() {
  Serial.print(name);
  Serial.print(" , ");
  Serial.println(midiAddress);
}

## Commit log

2017-07-26 combining MOM and MOL
    [Livedraw Redraw 2017-Lightbox-Webcam 02.dxf, Livedraw Redraw 2017-Lightbox-Webcam 03.dxf, Livedraw Redraw 2017-Lightbox-Webcam 04a.3dm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]
2017-07-26 PCB cleanup
    [MOL-v1-0.brd, MOL-v1.0.sch, MOL-v1.1-1.brd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]
2017-07-28 CAD updates big time
    [Joystick.brd, Joystick.dxf, Joystick.sch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]
2017-07-28 arduino nonsense
2017-07-31 changes to PCBs and CAD for MOL
    [MOL-holder_all-v3-4.dxf, MOL-v1.1-neck-v3-2a.dxf, MOL-v1.1d.dxf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]
2017-08-01 daniel tings
    [MOL-v2-1.brd, MOL-v2-1.sch]
2017-08-02 updates to MOL CAD
    [MOL-v1.1.dxf, MOL-v1_MOL-lightbox-bottom.dxf, MOL-v1_MOL-lightbox-mids.dxf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]
2017-08-03 changes to MOL cad
    [Button-profile.dxf, MOL-Button-Cap-1.stl, MOL-Button-Cap-Cap-1.stl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]
2017-08-09 python done
    [MOL-v2-2.brd, MOL-v2-2.sch]
2017-08-10 name change from MOL to MOD
    [Button-profile.dxf, Joystick.brd, Joystick.dxf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]
2017-08-17 added RPi power control circuitry
    [MOD-v2-2.brd]
2017-08-17 power control
2017-08-17 attiny added to MOD pcb
    [MOD-v2-2.brd, MOD-v2-2.sch]
2017-08-17 PCB MOD changes
2017-08-17 new MOD pcb
    [MOD-v2-2.1.brd, MOD-v2-2.1.sch]
2017-08-17 routed new MOD pcb v2-2.1
    [MOD-v2-2.1.brd]
2017-08-18 routed teensy breakout for MOD, v2-2.2.brd
    [MOD-v2-2.2.brd, MOD-v2-2.2.sch]
2017-08-18 routed teensy breakout for MOD, v2-2.2.brd updated
    [MOD-v2-2.2.brd, MOD-v2-2.2.sch]
2017-08-18 new version of MOD pcb v2-2, under 10cm by 10cm, removes resistor arrays, goes with MOD-strip 2-3
    [MOD-v2-3.brd, MOD-v2-3.sch, MOD-v2-3_MOD-Strips.brd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]
2017-08-18 tweaks to MOD pcb
    [MOD-v2-3.brd]
2017-08-20 new version of MO teensy breakout board, v2-3a
    [MOD-v2-3a.brd, MOD-v2-3a.sch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]
2017-08-20 DRC on MOD pcb v2-3a
    [MOD-v2-3a.brd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]
2017-08-21 jake suggestions to handle power transmission
    [MOD-v2-3b.brd, MOD-v2-3b.sch, MOD-v2-3c.brd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]
2017-08-21 all thru-hole parts, design checked by Jake and Daniel, re-routed with 24mil traces for power
    [MOD-v2-3c.brd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]
2017-09-11 new MOD teensy board
    [MOD-v2-3_MOD-Strips.brd, MOD-v2-3_MOD-Strips.sch, MOD-v2-3c.brd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]
2017-09-13 arduino refactor
    [MOD-v2-3.drills.xln]
2017-09-15 arduino code working
    [MOD-v2-5.brd, MOD-v2-5.sch]
2017-09-15 removing bad arduino stuff
2017-09-15 removed old MOM arduino stuff from Jesse
2017-09-15 board issues
2017-09-16 new boards
    [MOD-v2-4.dxf, MOD-v2-5.brd, MOD-v2-6.brd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]
2017-09-16 MOM CAD
    [MOD-v2-3_MOD-Strips.dxf, MOMv2.3dm]
2017-09-16 MOD-v2-5 routed
    [MOD-v2-4.brd, MOD-v2-5.brd, MOD-v2-5.sch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]
2017-09-16 new chassis for MOMv2
    [MOMv2.3dm, MOMv2_bottom-plate.dxf, MOMv2_top-bottom-plate.dxf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]
2017-09-16 names and versions to match
    [MOD-v2-5.brd]
2017-09-16 name changing
    [MOMv4.3dm]
2017-09-17 led flashes for mos
2017-09-17 LED flasher mo.led-flash
2017-09-17 no print
2017-09-17 changes to strip MOD and buttom caps
    [MOD-Button-Cap-Cap_v6.stl, MOD-Button-Cap-Frame_v4.stl, MOD-Button-Cap-Frame_v5.stl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]
2017-09-17 collected Pd dependencies into lib folder
    [MOD-Button-Cap-Cap_v7.stl]
2017-09-18 new buttons and caps, now in halves
    [MOD-Button-Cap-Cap_v8-A.stl, MOD-Button-Cap-Cap_v8-B.stl, MOD-Button-Cap-Cap_v9-A.stl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]
2017-09-19 re-organized PCB files, changed MOD to MO in PCB file names
    [Joystick.brd, Joystick.dxf, Joystick.sch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]
2017-09-19 minor change
    [MO-v2-5_MOD-Strips.sch]
2017-09-24 new routing for mo-pcb v2-5
2017-09-24 newly routed v2-5 breakout
    [MO-v2-5.brd]
2017-09-27 re-routed final versions of MO-2.5 and MO-strip-2.5, sent to Fusion
    [MO-v2-5.drills.xln, MO-v2-5_MOD-Strips.drills.xln]
2017-11-23 Pd additions, Arduino Fixes, MO Breakout Cosmetic issues and Midi renaming
    [MIDI.h, MO.h, MOM.ino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]
2017-11-23 Arduino motor inverse change to digitalWrite
2017-11-25 version 2.5 and 2.6 of MO pcbs both here now
    [MO-v2-6.brd, MO-v2-6.sch]
2017-11-27 new amotor board
    [MO-v2-2_MOD-Actuators.brd, MO-v2-2_MOD-Actuators.sch]
2017-12-15 new pcb boards and pd patches
    [MO-bela-lightspace-A.brd, MO-bela-lightspace-A.sch, MO-v2-7.brd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]
2017-12-16 lightbox for bela
    [MO-bela-lightspace-A.brd, MO-bela-lightspace-A.sch, MO-bela-lightspace-B.brd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]
2017-12-16 lightrect dxf added
    [MO-bela-lightspace-A.dxf]
2017-12-18 Raspi Power
2017-12-19 pcb and cad changes for mom
    [MO-v2-5_MOD-Strips.dxf, MOMv4_PCB-v2.6_01.dxf]
2017-12-21 new cad modesl for mom
    [Clamp-female-2.stl, Clamp-male-2.stl, Clamp-part1_2.stl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]
2017-12-22 new clamp for MOM
    [Clamp-female-3.stl, Clamp-female-4.stl, Clamp-male-3.stl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]
2018-03-02 new Arduino Project
2018-03-19 added software PWM

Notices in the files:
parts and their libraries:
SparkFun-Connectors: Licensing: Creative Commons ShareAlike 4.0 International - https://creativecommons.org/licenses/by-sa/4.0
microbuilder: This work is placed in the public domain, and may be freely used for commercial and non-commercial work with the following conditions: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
